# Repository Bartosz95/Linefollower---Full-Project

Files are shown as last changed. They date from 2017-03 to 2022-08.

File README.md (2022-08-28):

# Linefollowers

# Abstract 
Current repository contains three of my line follower projects.
Linefollower is a mobile robot which follows the line.
My robots were built for competitions so the main aim was to allow them to move fast.
Some of them were also remote controlled.
I've created these robots from top to bottom myself it means that I designed a board, created it, solder elements, create program for CPU and install it.

# Technologies
- KiCad
- STM32CubeMX
- Qt

# Description
As I mentioned current directory contains three robots
- BEBO - my first line follower which has PID algorithm
- LFANT - line follower which has spread encoders and mesure his speed
- Remote Controlled - this one is controlled by desktop remote app
To create these robots I had to do the same steps which I described below.

## Hardware
First I have to design a board. I've used a KiCad application to do it.
During this process I had to choose a CPU, engines, bridge for engine, battery, line sensors and all necessary elements.
I have chosen CPU STM32F051C8Tx because is enough small, 2 Pololu 10:1 engines, TB6612 bridge, Li-Pol 7,4V battery, line sensor KTIR0711s and depending on project AS5048A encoders or HC-06 bluetooth module.
Below you can see what it looks like designed boards ready to create.
<p align="center" float="left">
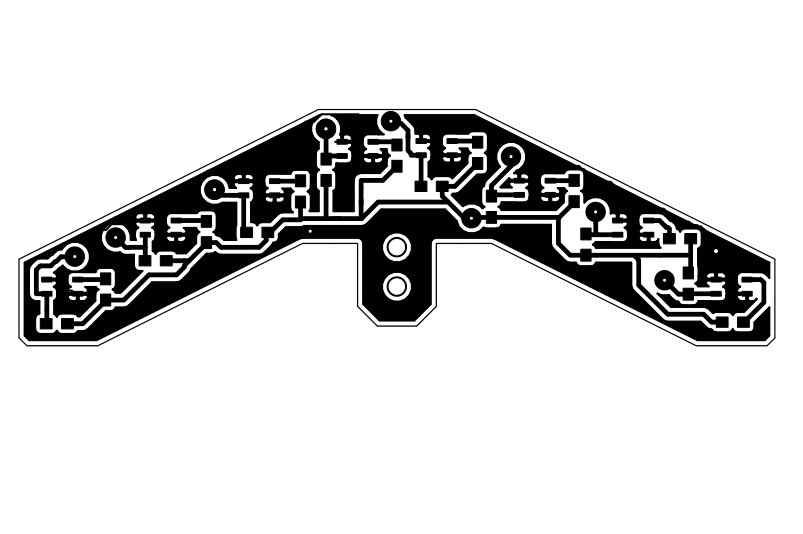
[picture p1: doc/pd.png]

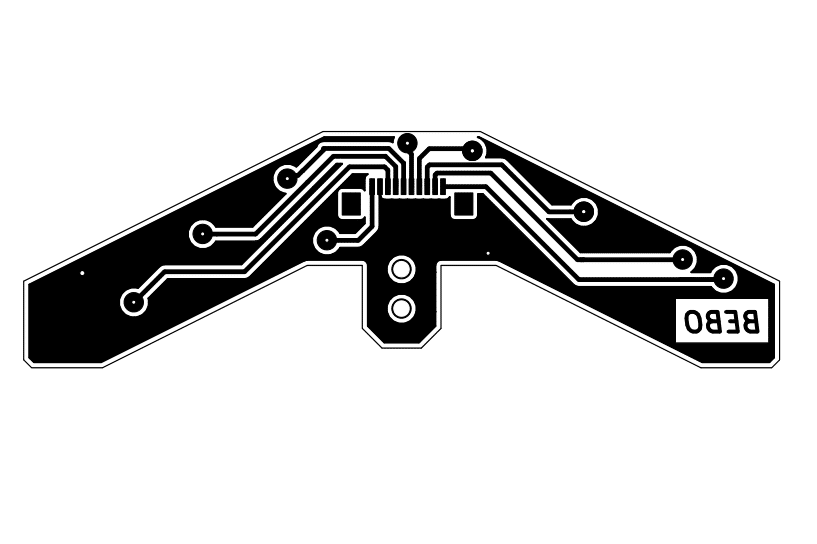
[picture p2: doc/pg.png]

</p>
<p align="center" float="left">
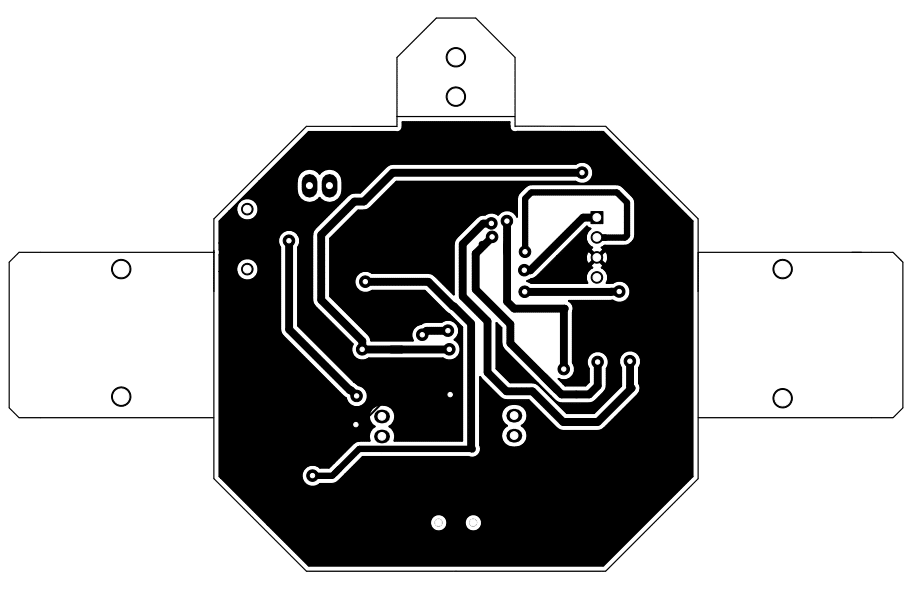
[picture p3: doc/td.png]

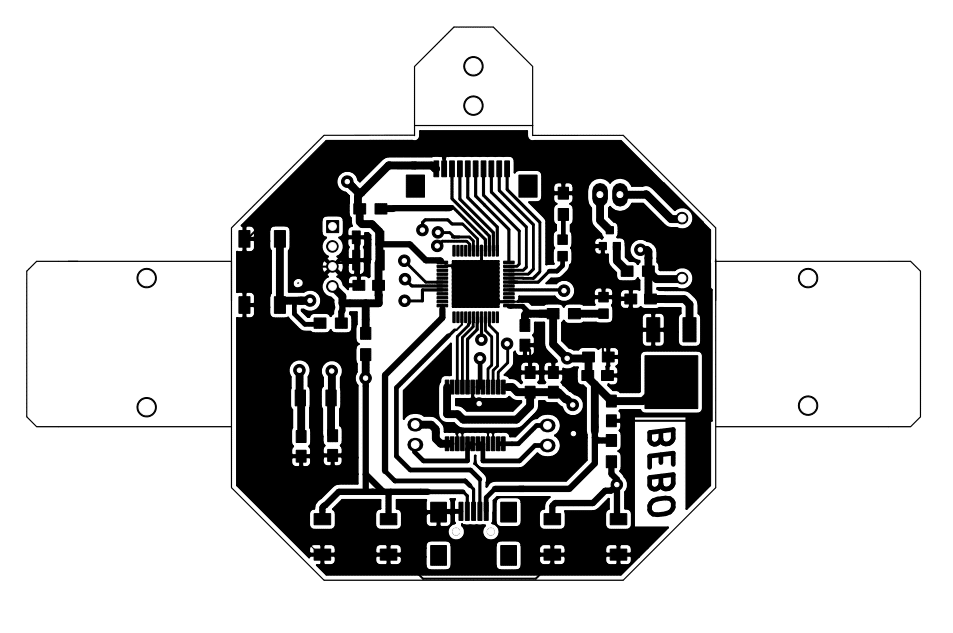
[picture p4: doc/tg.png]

</p>
In the next step I have to create this board and solder elements.
All
<p align="center" float="left">
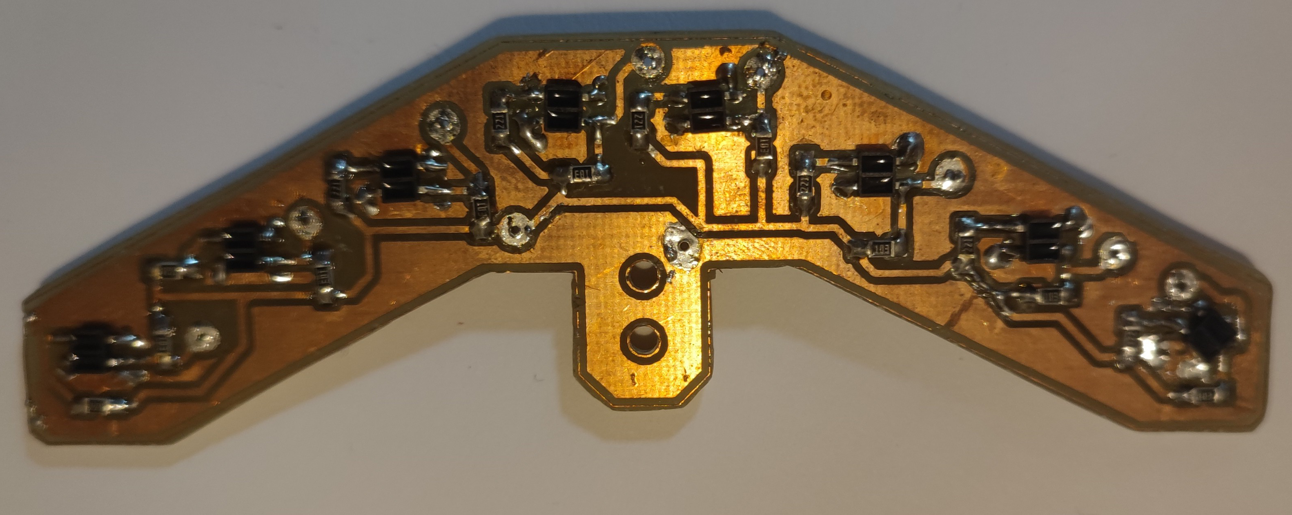
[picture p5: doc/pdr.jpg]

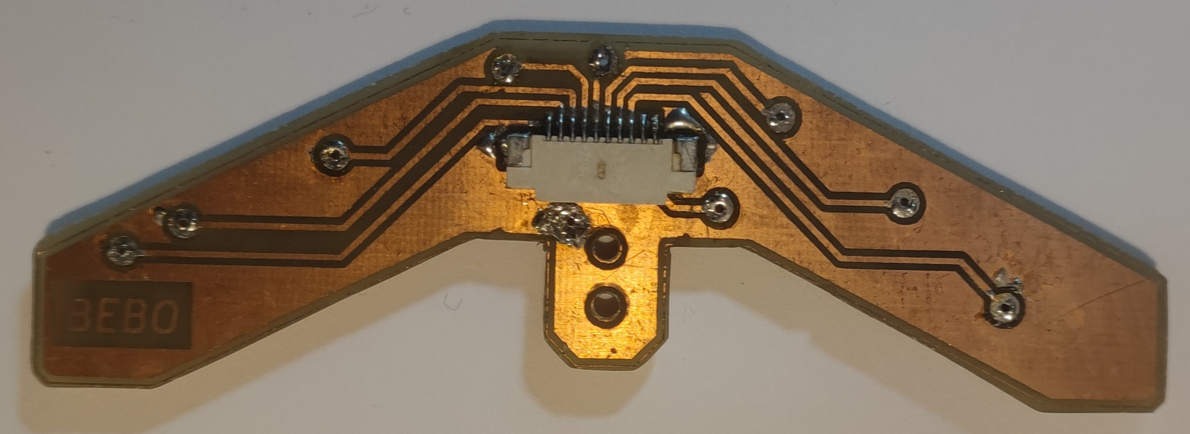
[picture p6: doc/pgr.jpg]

</p>
## Software
For creating software I decided to use the STM32CubeMX application.
It allows you to create programs for STM processors easily.
I assigned all necessary pins to the processor and created a controlled program.
When I finished programming it, I installed a program on robots by programator located on the STM32F4 board.
Created connection looks like below.
<p align="center" float="left">
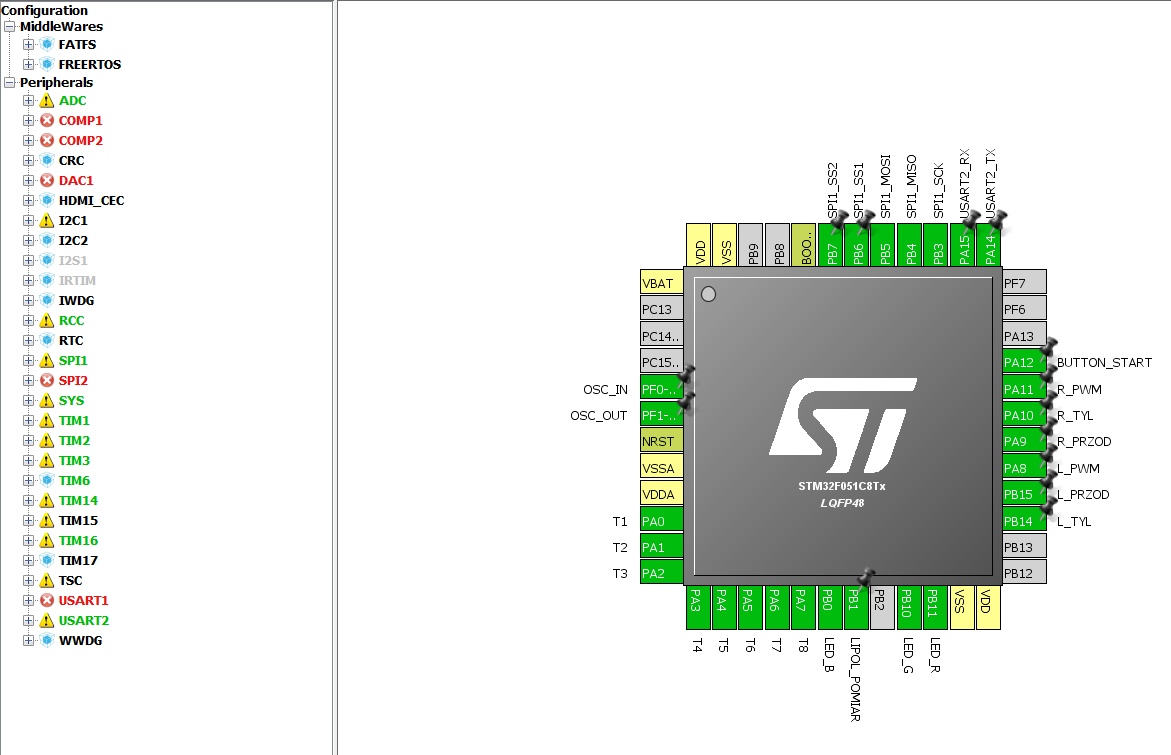
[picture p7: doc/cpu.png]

</p>
Ready robot looks like below.
<p align="center" float="left">
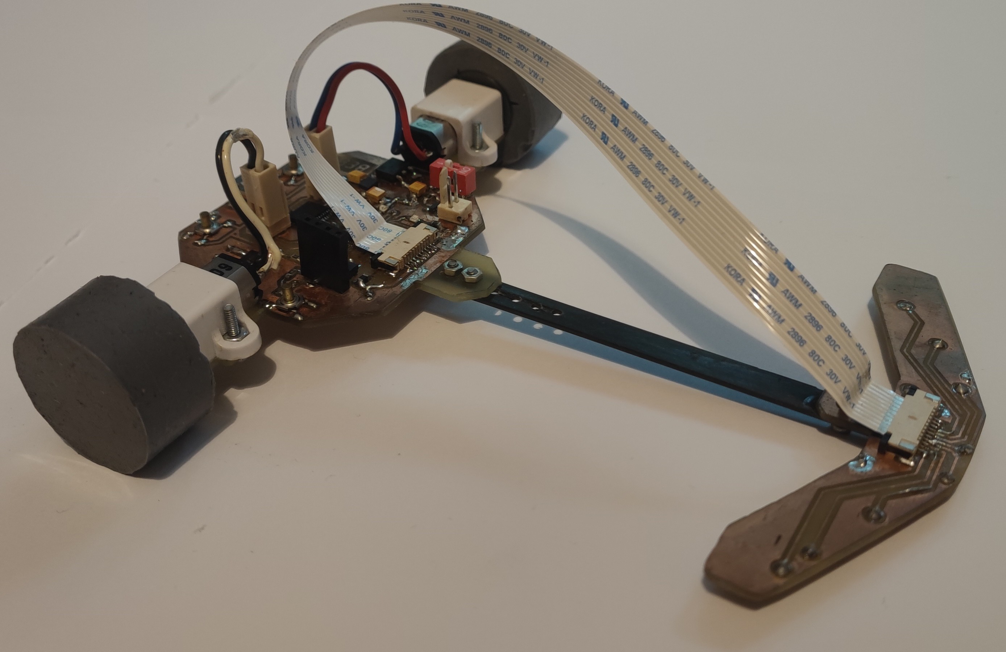
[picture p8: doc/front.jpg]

</p>
<p align="center" float="left">
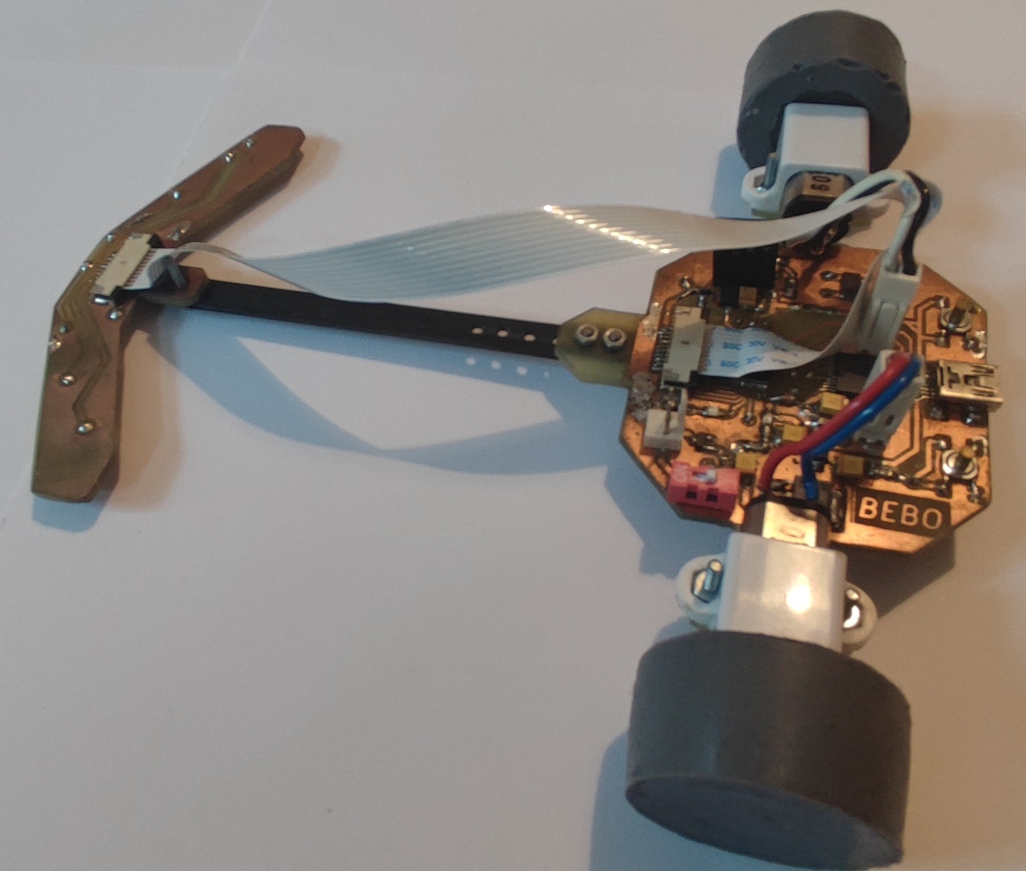
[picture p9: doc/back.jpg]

</p>

# Desktop application
For a remote controlled robot I created a program in C++ Qt. 
The connection works through bluetooth. Program works below.
The main window of the program is split vertically.
On the left side you can see measurements from the line follower.
On the right you have a control panel.
If each sensor detects a black line the circle of the top will change to black.
Below grey rectangles you can see 0. When a robot is moving it shows speed in mps.
In the control panel you have 5 buttons.
The one on the top change remote controlling to automatic control by PID algorithm,
The next four allow remote control robots. 
<p align="center" float="left">
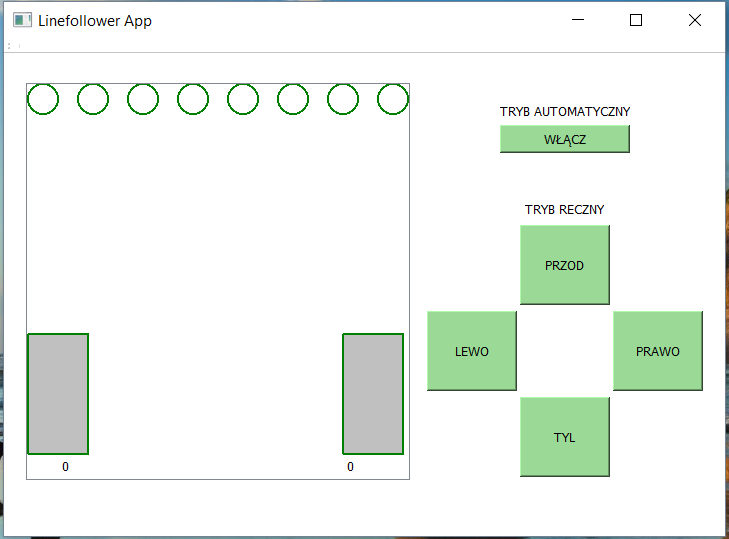
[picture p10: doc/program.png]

</p>

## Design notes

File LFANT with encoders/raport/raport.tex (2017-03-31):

% Definicja klasy dokumentu
\documentclass[12pt,a4paper]{article}

%------------------------------------
% 			Pakiety
\usepackage[utf8x]{inputenc}
\usepackage{ucs}
\usepackage[MeX]{polski}
\usepackage{fancyhdr}
\usepackage{amsmath}
\usepackage{amsfonts}
\usepackage{amssymb}
\usepackage[hidelinks]{hyperref}
\usepackage{graphicx}
\pagestyle{fancy}

%---------------------------------------
% 		Dodanie strony tytulowej do dokumentu
\input{tytulowa.tex} 

%-----------------------------------------
% 		Poczatek dokumentu
\begin{document}
\maketitle % Komenda maktitle dodaje stronę tytułową do dokumentu głównego
\tableofcontents % Komenda tableofcontents dodaje spis treści do dokumentu głównego
\newpage % Komenda newpage przechodzi do nowej strony w dokumencie.

%				Dokument wlasciwy
\section{Wstęp}

Celem projektu jest wykonanie robota mobilnego klasy linefollower. Zadaniem tego robota jest poruszanie się po czarnej linii na białym tle. Robot ma mieścić się na kartce A4. 

Robot będzie posiadał dwa enkodery AS5048A i komunikował się z nimi za pomocą interfejsu SPI.

\section{Założenia projektowe}
\begin{itemize}

\item Robot będzie składał się z 2 części - płytki głównej, na której będzie znajdował się mikrokontroler wraz z resztą elektroniki i akumulatorem oraz z płytki, na której będą czujniki odbiciowe. 

\item Napęd robota będą stanowiły 2 silniki Pololu.

\item Robot będzie zasilany przez akumulator Li-Pol o napięciu 7,4V i pojemności 300mAh.

\item Zabezpieczenie przed odwrotną polaryzacją w postaci tranzystora MOSFET oraz zabezpieczenie prądowe.

\item Pomiar napięcia baterii - sygnalizacja rozładowania się w postaci diody.

\item Projekt oparty o mikrokontroler STM32F051C8Tx, ponieważ jest mały, a posiada wystarczającą ilość potrzebnych peryferii.

\item 8 czujników odbiciowych KTIR0711s do wykrywania czarnej linii.

\item Silniki sterowane poprzez mostek TB6612.

\item Komunikacja z robotem będzie odbywała się przez moduł Bluetooth. 

\item 2 enkodery AS5048A obsługiwane za pomocą SPI.

Gdy uda się zrealizować powyższe założenia, w planie jest opcjonalne rozszerzenie projektu o dodanie:

\item turbiny ssącej

\item czujników odległośći Sharp

\end{itemize}

\section{Plan pracy}

\subsection{Harmonogram}

\begin{itemize}

\item Zaprojektowanie schematu - 16.04.2017

\item Zaprojektowanie płytki PCB - 7.05.2017

\item Wytrawiona i polutowana płytka - 14.05.2017

\item Wstępne zaprogramowanie robota - 4.06.2017

\item Testy gotowego programu - 18.06.2017

\item Raport końcowy - 22.06.2017

\end{itemize}

\subsection{Kamienie milowe}

\begin{itemize}
\item Zaprojektowana schematu - 16.04.2017

\item Rozpoczęcie programowania robota - 15.05.2017

\item Gotowy projekt wraz z raportem - 22.06.2017
\end{itemize}

\bibliographystyle{plunsrt}
\bibliography{mybib}
\clearpage
\end{document}

%Wzór numerowania

%\section{Punkt}
%\subsection{Podpunkt}

%Wzór dodawania obrazu

%\includegraphics[width=1\textwidth]{lipol.png}
%\caption{Schemat akumulatora \label{fig:lipol}}
%\end{figure}
%\begin{figure}[tp]
%\centering
%\includegraphics[width=1\textwidth]{stabilizator.png}
%\caption{Schemat stabilizatorów \label{fig:stabilizator}}
%\end{figure}

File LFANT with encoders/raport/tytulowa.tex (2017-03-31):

\renewcommand{\maketitle}{\begin{titlepage}

\begin{center}
%\vspace*{0.7cm}
\large \textsc{POLITECHNIKA WROCŁAWSKA}\\
\large \textsc{WYDZIAŁ ELEKTRONIKI}\\
\vspace*{4.7cm}
\huge \textsc{Sterowniki Robotów}\\
\vspace*{0.7cm}
\LARGE \textsc{Robot mobilny klasy linefollower}
\vspace*{0.7cm}

\vspace*{3cm}

\large

\textsc{Bartosz Lenartowicz} \\
\textsc{Magdalena Kaczorowska} \\

\vspace*{6cm}
\textsc{Wrocław, \today}\\
\end{center}
\end{titlepage}
\newpage
}

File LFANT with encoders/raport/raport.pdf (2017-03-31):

POLITECHNIKA WROCŁAWSKA

WYDZIAŁ ELEKTRONIKI

### Sterowniki Robotów

Robot mobilny klasy linefollower

Bartosz Lenartowicz

Magdalena Kaczorowska

Wrocław, 31 marca 2017

SPIS TREŚCI | SPIS TREŚCI

## Spis treści

1 Wstęp | 2
2 Założenia projektowe | 2
3 Plan pracy | 3

1

2 ZAŁOŻENIA PROJEKTOWE

## 1 Wstęp

Celem projektu jest wykonanie robota mobilnego klasy linefollower. Zadaniem tego robota jest poruszanie się po czarnej linii na białym tle. Robot ma mieścić się na kartce A4.
Robot będzie posiadał dwa enkodery AS5048A i komunikował się z nimi za pomocą interfejsu SPI.

## 2 Założenia projektowe

- Robot będzie składał się z 2 części - płytki głównej, na której będzie znajdował się mikrokontroler wraz z resztą elektroniki i akumulatorem oraz z płytki, na której będą czujniki odbiciowe.
- Napęd robota będą stanowiły 2 silniki Pololu.
- Robot będzie zasilany przez akumulator Li-Pol o napięciu 7,4V i pojemności 300mAh.
- Zabezpieczenie przed odwrotną polaryzacją w postaci tranzystora MOS-FET oraz zabezpieczenie prądowe.
- Pomiar napięcia baterii - sygnalizacja rozładowania się w postaci diody.
- Projekt oparty o mikrokontroler STM32F051C8Tx, ponieważ jest mały, a posiada wystarczającą ilość potrzebnych peryferii.
- 8 czujników odbiciowych KTIR0711s do wykrywania czarnej linii.
- Silniki sterowane poprzez mostek TB6612.
- Komunikacja z robotem będzie odbywała się przez moduł Bluetooth.
- 2 enkodery AS5048A obsługiwane za pomocą SPI.

Gdy uda się zrealizować powyższe założenia, w planie jest opcjonalne rozszerzenie projektu o dodanie:

- turbiny ssącej
- czujników odległośći Sharp

2

3 PLAN PRACY

## 3 Plan pracy

### 3.1 Harmonogram

- Zaprojektowanie schematu - 16.04.2017
- Zaprojektowanie płytki PCB - 7.05.2017
- Wytrawiona i polutowana płytka - 14.05.2017
- Wstępne zaprogramowanie robota - 4.06.2017
- Testy gotowego programu - 18.06.2017
- Raport końcowy - 22.06.2017

### 3.2 Kamienie milowe

- Zaprojektowana schematu - 16.04.2017
- Rozpoczęcie programowania robota - 15.05.2017
- Gotowy projekt wraz z raportem - 22.06.2017

3

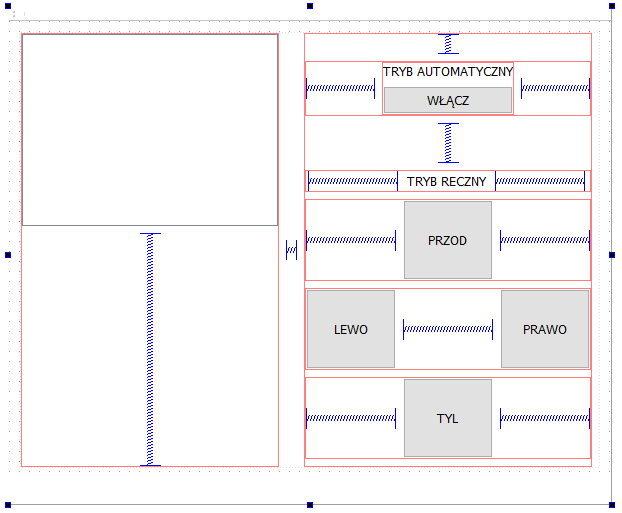
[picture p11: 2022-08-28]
doc/Okno.PNG

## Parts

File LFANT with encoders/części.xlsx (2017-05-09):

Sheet: Arkusz1
Botland
Nazwa | ilosc | cena za sztukę | razem
Silnik Pololu | 2 | 72 | 144
Ball Caster | 2 | 7.9 | 15.8
KTIR0711S | 10 | 1.95 | 19.5
mocowanie silnika | 1 | 17.9 | 17.9
Razem: |  |  | 197.2
Nie wybrane
bezpiecznik
przelacznik on/off

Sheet: Arkusz2
Elektropark
Nazwa | ilosc | cena za sztukę | razem
TB6612 | 2 | 13.99 | 27.98
LED Biała | 3 | 0.49 | 1.47
LED RGB | 1 | 0.99 | 0.99
Kwarc 8MHz | 3 | 1.8 | 5.4
Taśma FFC 11cm | 1 | 3.51 | 3.51
Taśma FFC 21cm | 1 | 4.4 | 4.4
Złącze FFC/FPC | 2 | 2.5 | 5
Przełącznik ON/ON | 2 | 2.24 | 4.48
IRML0030 N Mosfet | 3 | 0.69 | 2.07
R33k | 1 | 0.3 | 0.3
R47k | 2 | 0.3 | 0.6
R1k | 1 | 0.3 | 0.3
R220R | 3 | 0.3 | 0.9
R10k | 5 | 0.3 | 1.5
R1k | 1 | 0.3 | 0.3
R150k | 1 | 0.3 | 0.3
R13k | 1 | 0.3 | 0.3
R22k | 1 | 0.3 | 0.3
R62k | 1 | 0.3 | 0.3
USB typ B smd mini | 3 | 1.01 | 3.03
C22pF | 1 | 0.39 | 0.39
C100nF | 2 | 0.39 | 0.78
C10nF | 1 | 0.45 | 0.45
C4,7 | 2 | 0.85 | 1.7
C10uF | 2 | 0.8 | 1.6
LF33 3.3V | 3 | 3 | 9
LM1117 5V | 3 | 1.35 | 4.05
Laminat św/150x200/2 | 1 | 42.99 | 42.99
Laminat św/75x100/2 | 1 | 9 | 9
Razem: |  |  | 133.39

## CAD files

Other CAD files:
LFANT with encoders/Inventor/mocowania_magnesów.ipt

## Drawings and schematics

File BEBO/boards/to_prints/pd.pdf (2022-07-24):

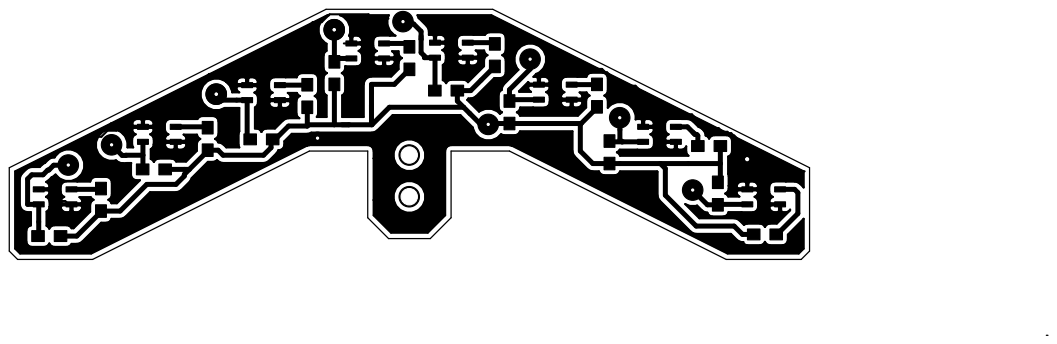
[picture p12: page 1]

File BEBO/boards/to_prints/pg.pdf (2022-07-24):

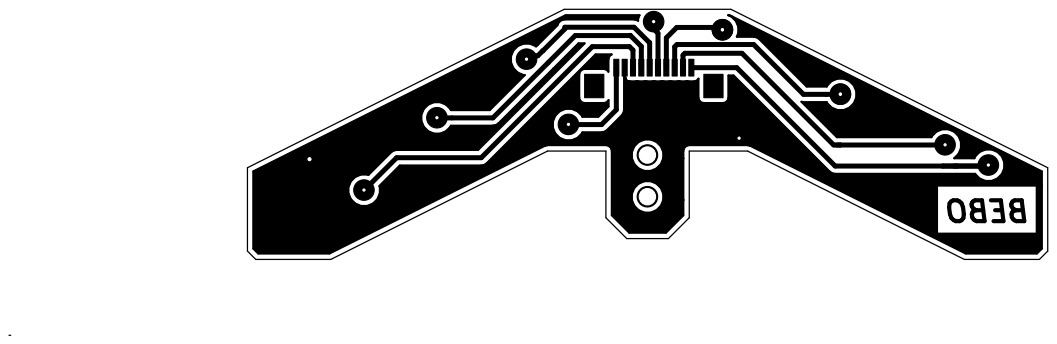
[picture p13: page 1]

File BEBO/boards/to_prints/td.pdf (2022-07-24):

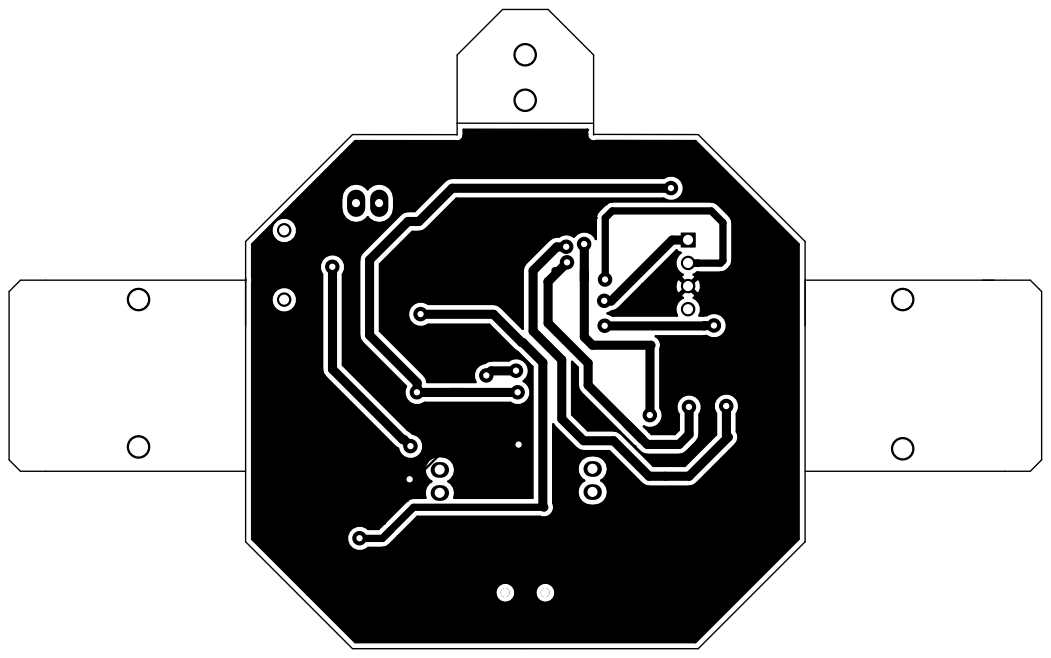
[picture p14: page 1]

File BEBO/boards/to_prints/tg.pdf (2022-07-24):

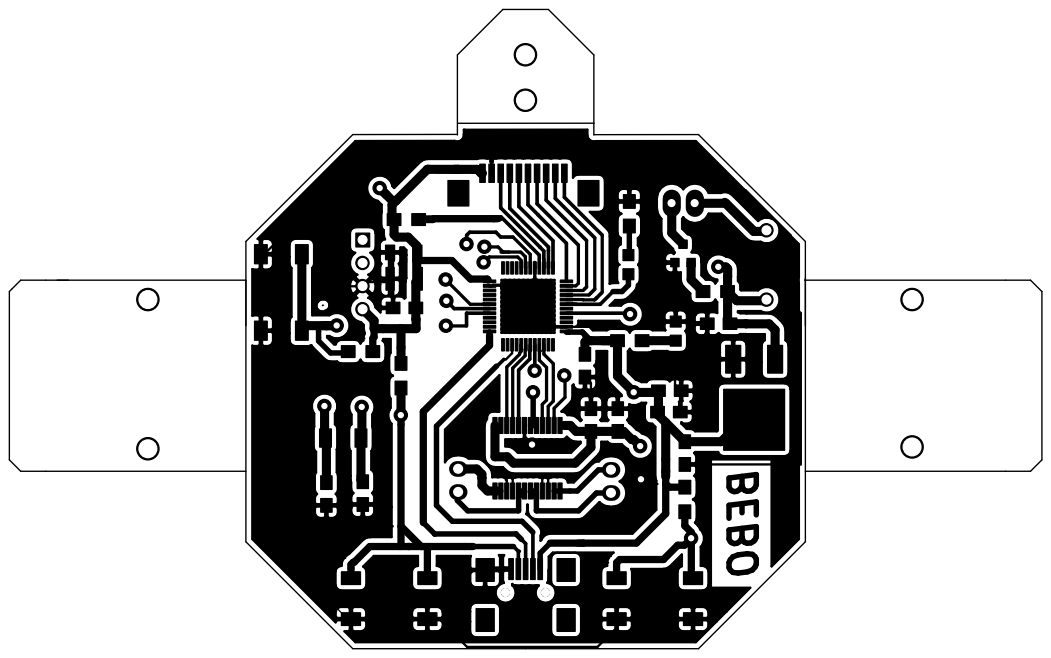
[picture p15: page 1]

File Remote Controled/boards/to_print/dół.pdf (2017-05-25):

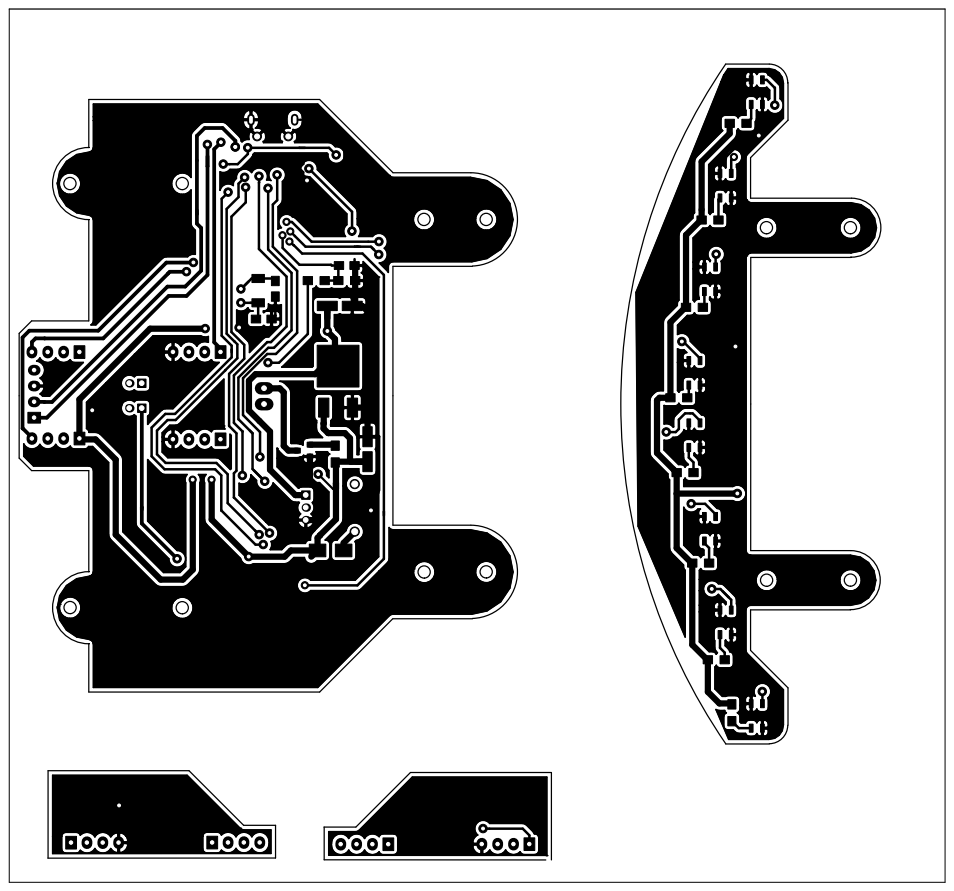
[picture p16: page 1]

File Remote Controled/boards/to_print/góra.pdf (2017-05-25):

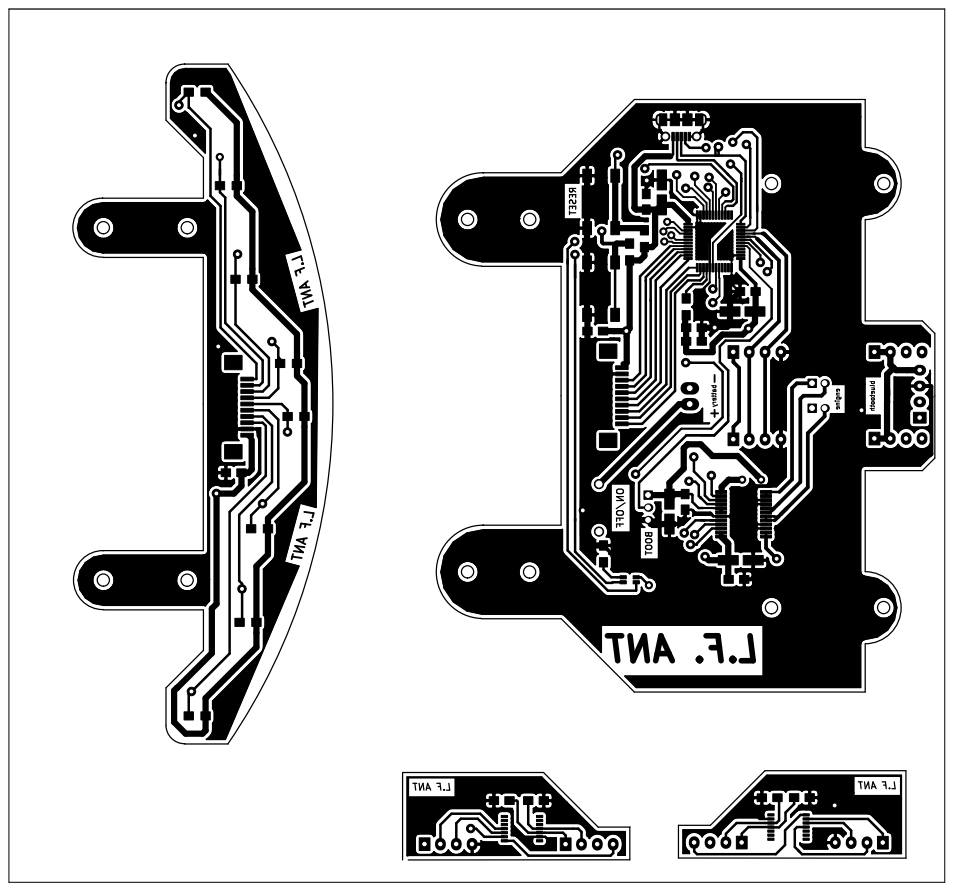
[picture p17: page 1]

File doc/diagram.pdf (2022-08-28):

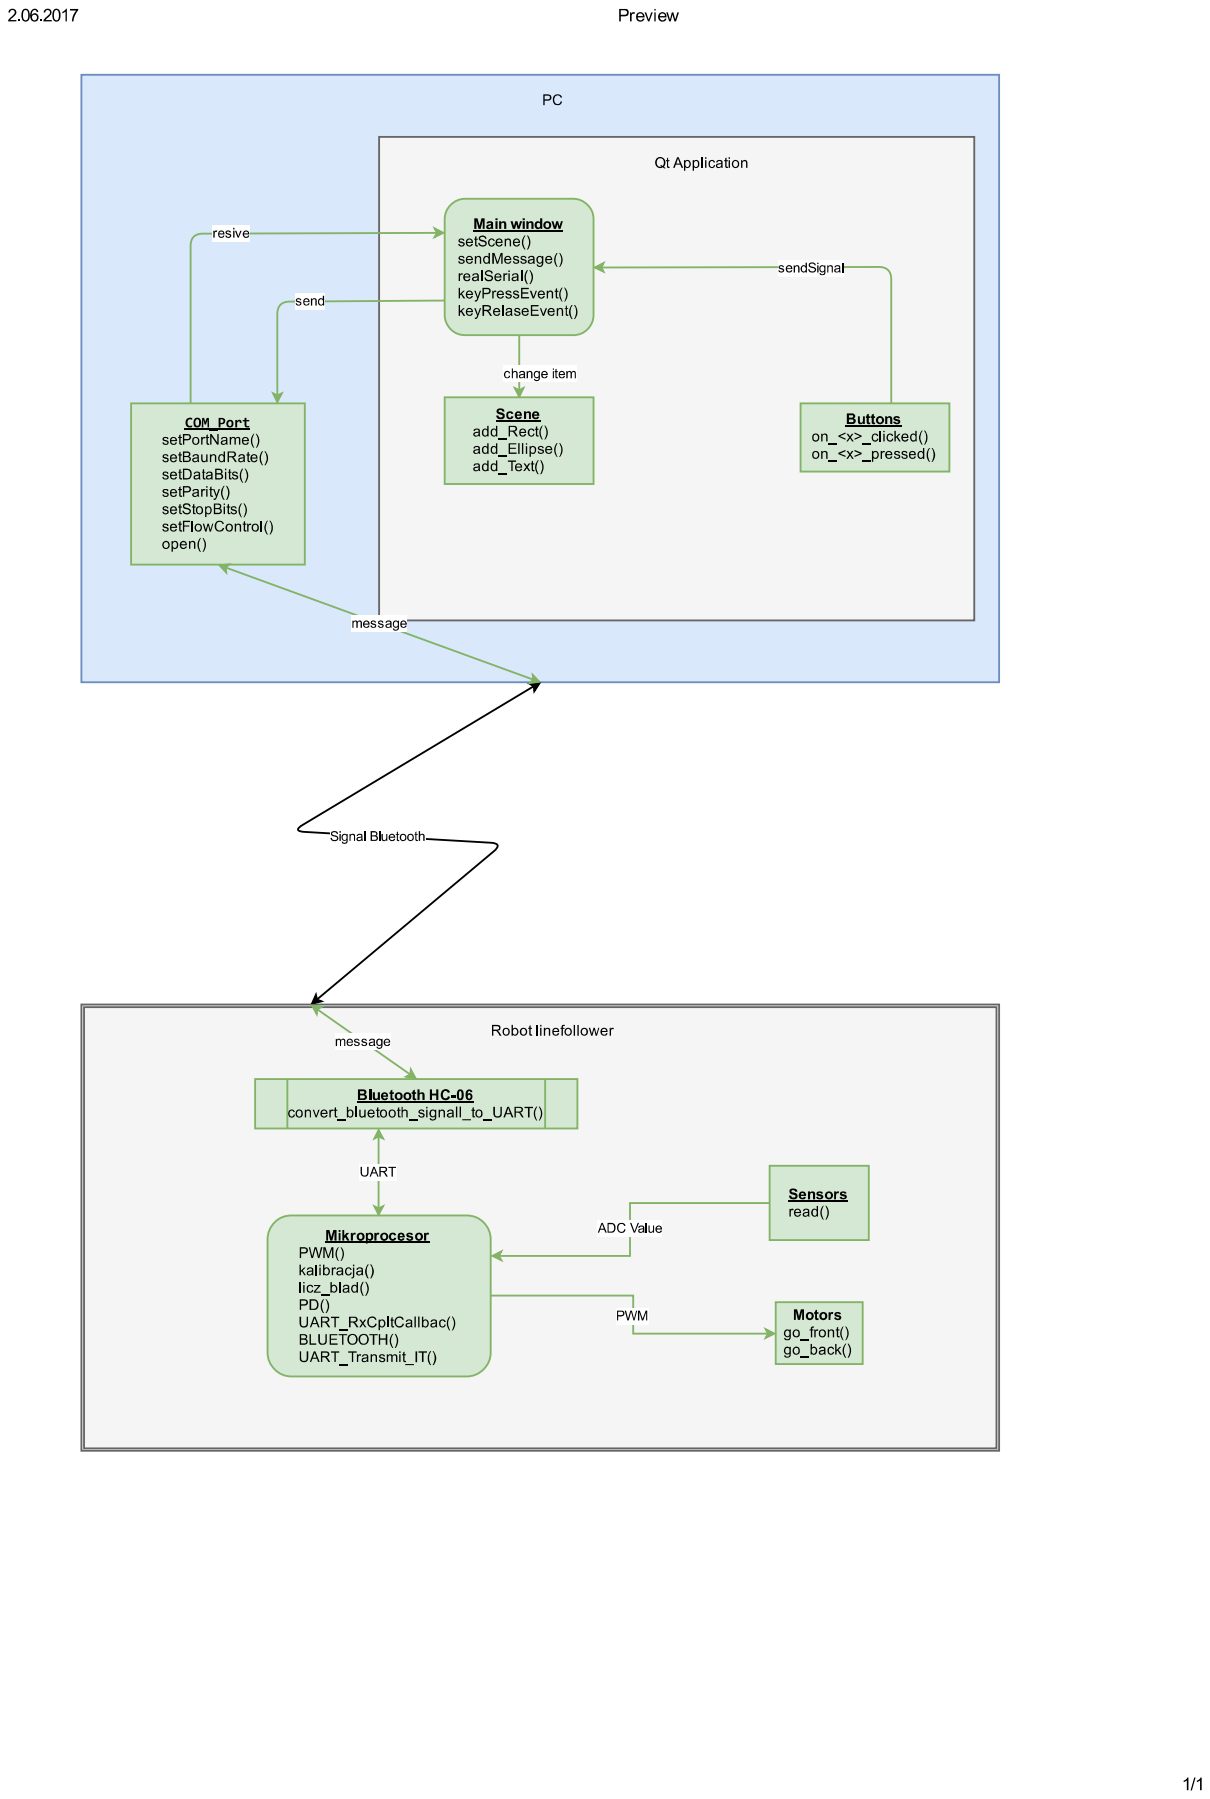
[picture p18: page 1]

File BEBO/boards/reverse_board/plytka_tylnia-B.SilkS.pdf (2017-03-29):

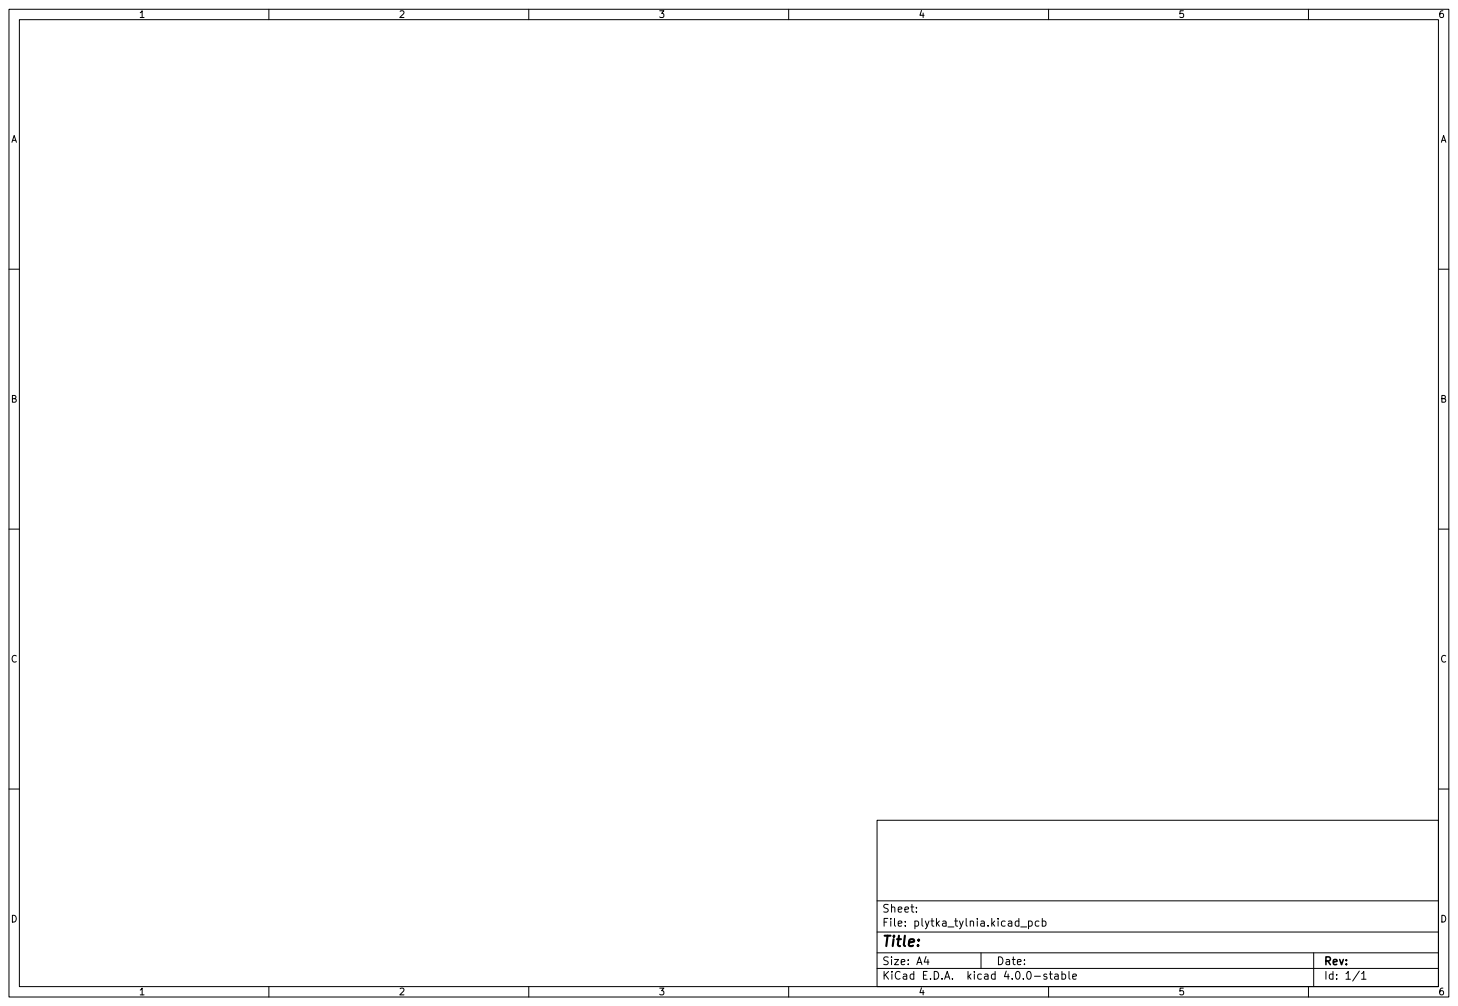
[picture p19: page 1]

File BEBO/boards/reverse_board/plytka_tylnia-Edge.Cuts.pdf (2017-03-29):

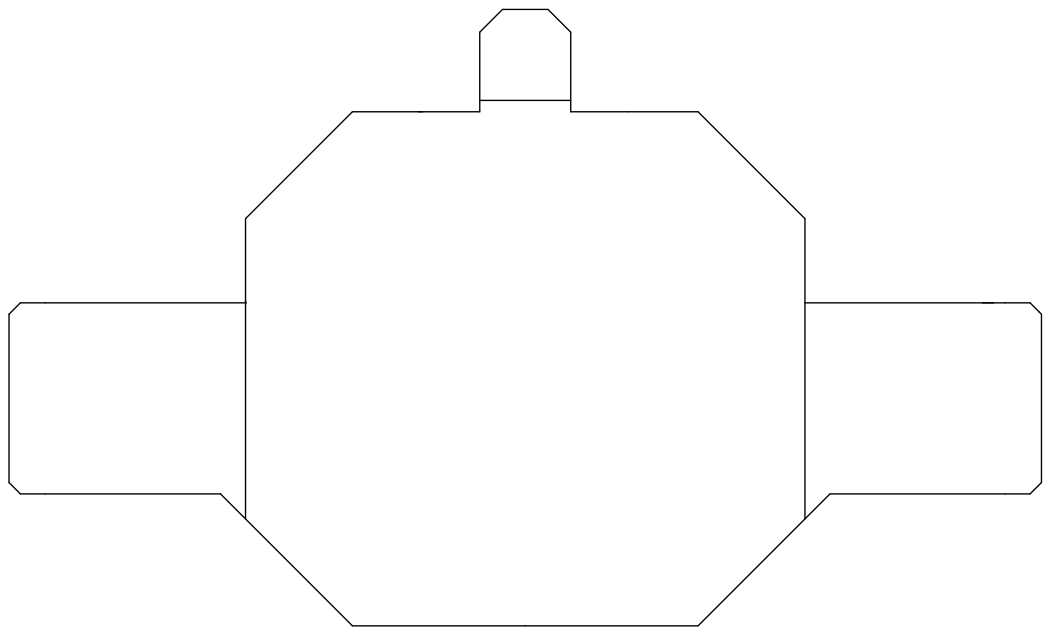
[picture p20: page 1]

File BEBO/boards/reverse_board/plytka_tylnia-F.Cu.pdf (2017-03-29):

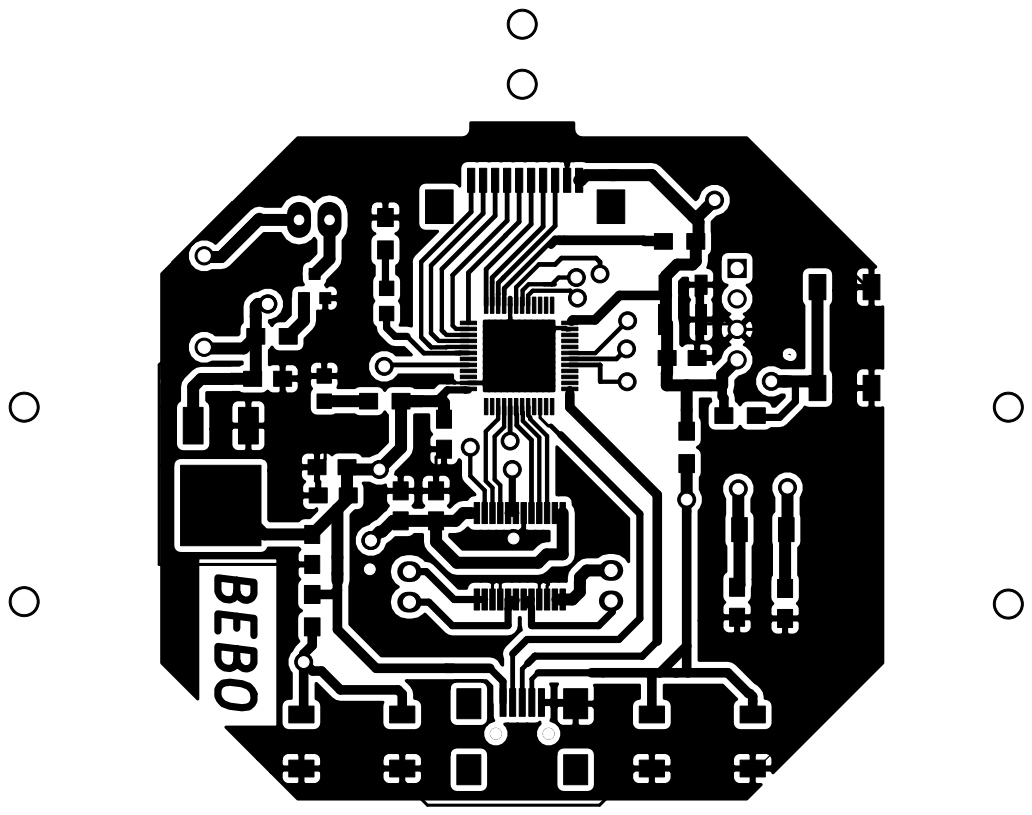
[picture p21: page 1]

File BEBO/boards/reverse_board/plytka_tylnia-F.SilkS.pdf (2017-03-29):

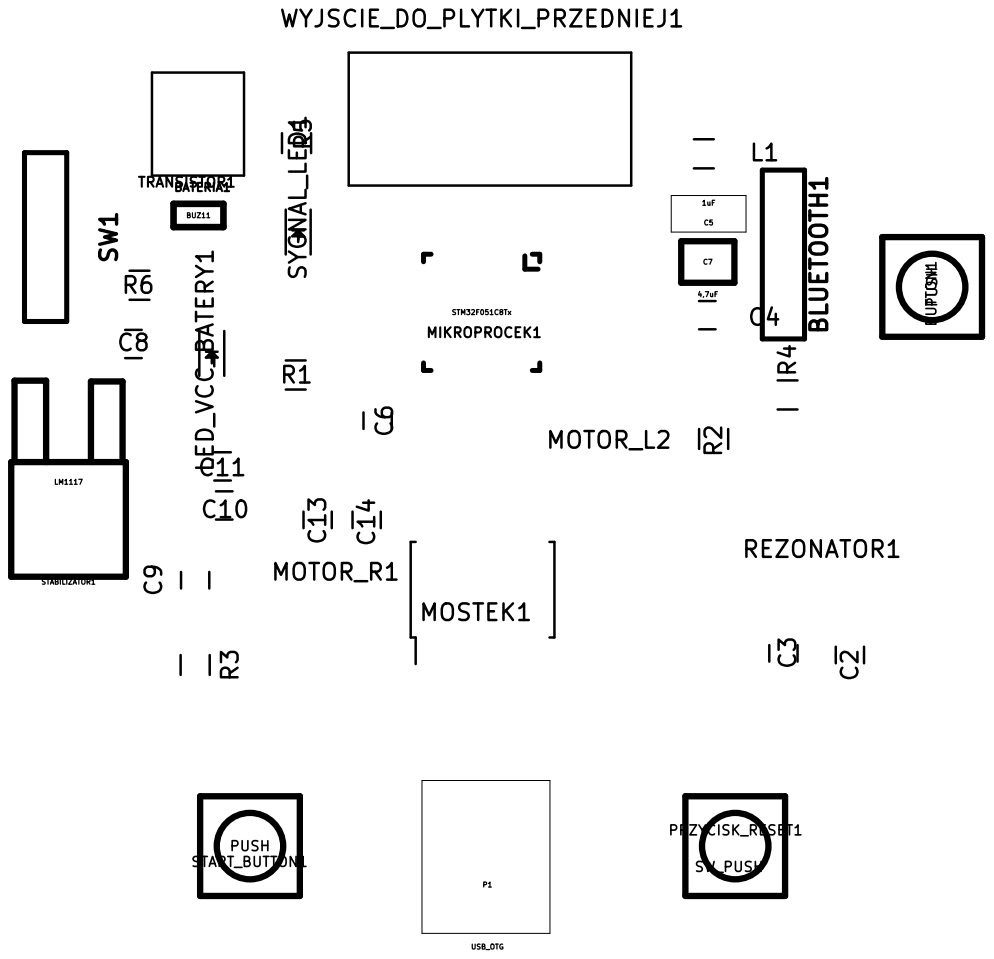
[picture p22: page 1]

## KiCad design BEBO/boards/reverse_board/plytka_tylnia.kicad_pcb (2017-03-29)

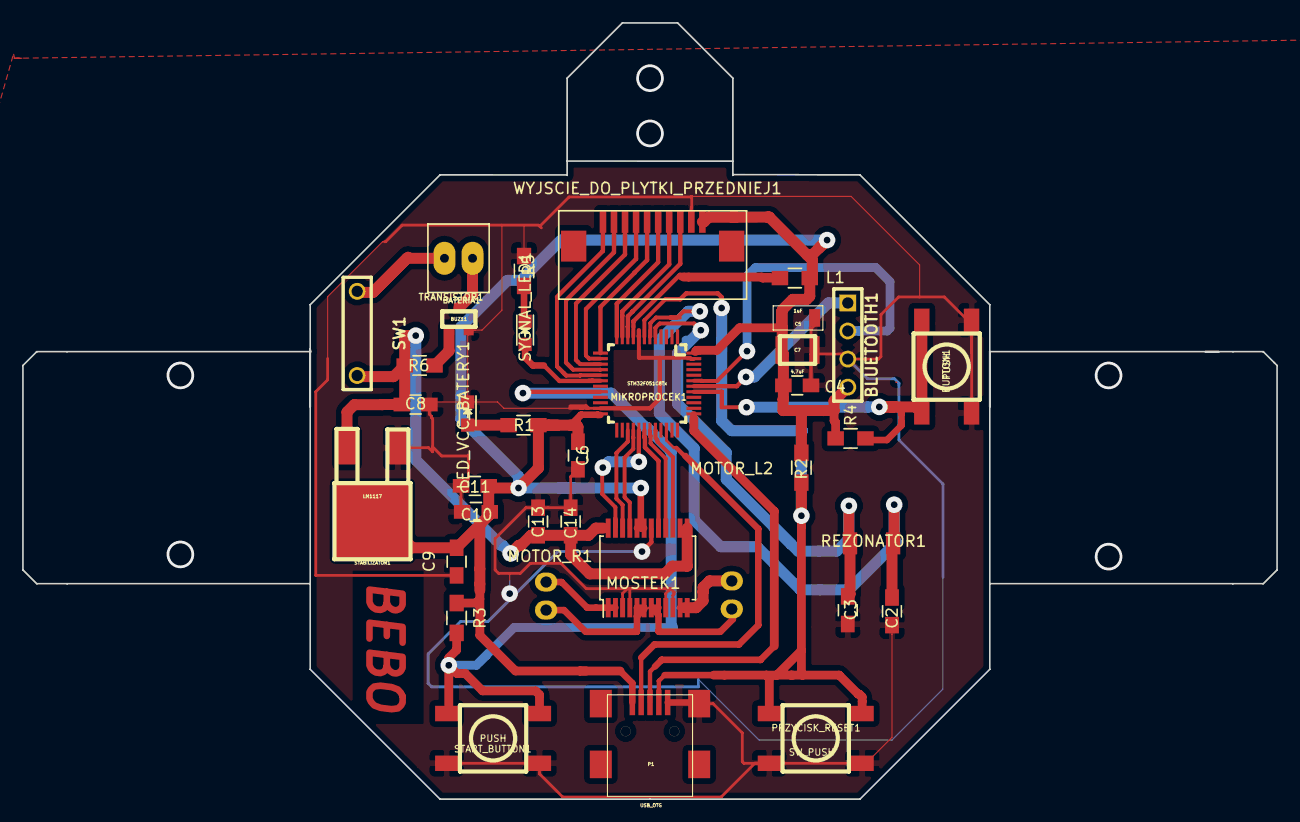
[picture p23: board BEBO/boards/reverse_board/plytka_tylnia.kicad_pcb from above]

Board: 2 copper layers, 113.5 x 70.2 mm, 36 parts (0 on the bottom side), 37 nets.

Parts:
BATERIA1: LI-POL; zl_zasilania
BLUETOOTH1: PIN4; pin_array_4x1
BUTTON1: PUSH; SW_06_SMD
C2, C3: 22pF; C_0805_HandSoldering
C4: 10nF; C_0805_HandSoldering
C5: 1uF; 1206
C6: 100nF; C_0805_HandSoldering
C7: 4,7uF; 1210
C8, C9, C11, C14: 10uF; C_0805_HandSoldering
C10: 1uF; C_0805_HandSoldering
C13: 0.1uF; C_0805_HandSoldering
L1: 10uH; R_0805_HandSoldering
LED_VCC_BATERY1: LED_GREEN; LED_0805
MIKROPROCEK1: STM32F051C8Tx; LQFP48
MOSTEK1: TB6612
MOTOR_L2: PIN2; silnik
MOTOR_R1: PIN2; silnik
P1: USB_OTG; USB-MINI-B-SMD
PRZYCISK_RESET1: SW_PUSH; SW_06_SMD
R1, R5: 200; R_0805_HandSoldering
R2, R3, R4: 10k; R_0805_HandSoldering
R6: 1k; R_0805_HandSoldering
REZONATOR1: HC49-S; Kwarc_SMD_Mini
STABILIZATOR1: LM1117; LM1117_TO-252
START_BUTTON1: PUSH; SW_06_SMD
SW1: SPST; dip_switch_1
SYGNAL_LED1: LED_BLUE; LED_0805
TRANSISTOR1: BUZ11; SOT23-3
WYJSCIE_DO_PLYTKI_PRZEDNIEJ1: PIN10; fpc_10_pin

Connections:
/BATERIA: C8.1, C13.2, C14.1, MOSTEK1.13, MOSTEK1.14, MOSTEK1.24, R6.2, STABILIZATOR1.1, SW1.2
/L_IN1: MIKROPROCEK1.27, MOSTEK1.22
/L_IN2: MIKROPROCEK1.28, MOSTEK1.21
/L_PWM: MIKROPROCEK1.29, MOSTEK1.23
/RESET: MIKROPROCEK1.7, P1.4, PRZYCISK_RESET1.1, R2.2
/R_IN1: MIKROPROCEK1.31, MOSTEK1.16
/R_IN2: MIKROPROCEK1.30, MOSTEK1.17
/R_PWM: MIKROPROCEK1.32, MOSTEK1.15
/SWCLK: MIKROPROCEK1.37, P1.3
/SWDIO: MIKROPROCEK1.34, P1.2
/T1: MIKROPROCEK1.10, WYJSCIE_DO_PLYTKI_PRZEDNIEJ1.8
/T2: MIKROPROCEK1.11, WYJSCIE_DO_PLYTKI_PRZEDNIEJ1.7
/T3: MIKROPROCEK1.12, WYJSCIE_DO_PLYTKI_PRZEDNIEJ1.6
/T4: MIKROPROCEK1.13, WYJSCIE_DO_PLYTKI_PRZEDNIEJ1.5
/T5: MIKROPROCEK1.14, WYJSCIE_DO_PLYTKI_PRZEDNIEJ1.4
/T6: MIKROPROCEK1.15, WYJSCIE_DO_PLYTKI_PRZEDNIEJ1.3
/T7: MIKROPROCEK1.16, WYJSCIE_DO_PLYTKI_PRZEDNIEJ1.2
/T8: MIKROPROCEK1.17, WYJSCIE_DO_PLYTKI_PRZEDNIEJ1.1
/USART_RX: BLUETOOTH1.1, MIKROPROCEK1.42
/USART_TX: BLUETOOTH1.2, MIKROPROCEK1.43
GND: BLUETOOTH1.3, BUTTON1.1, C2.2, C3.2, C4.2, C5.2, C6.2, C7.2, C8.2, C9.2, C10.2, C11.1, C13.1, C14.2, LED_VCC_BATERY1.1, MIKROPROCEK1.8, MIKROPROCEK1.23, MIKROPROCEK1.47, MOSTEK1.3, MOSTEK1.4, MOSTEK1.9, MOSTEK1.10, MOSTEK1.18, P1.5, P1.6, PRZYCISK_RESET1.2, R5.2, STABILIZATOR1.3, START_BUTTON1.1, TRANSISTOR1.2, WYJSCIE_DO_PLYTKI_PRZEDNIEJ1.9
unnamed: BATERIA1.1, TRANSISTOR1.3
unnamed: BATERIA1.2, SW1.1
unnamed: BUTTON1.2, MIKROPROCEK1.41, R4.2
unnamed: C3.1, MIKROPROCEK1.5, REZONATOR1.1
unnamed: C2.1, MIKROPROCEK1.6, REZONATOR1.2
unnamed: R6.1, TRANSISTOR1.1
unnamed: L1.2, MIKROPROCEK1.9
unnamed: LED_VCC_BATERY1.2, R1.1
unnamed: MIKROPROCEK1.20, R3.2, START_BUTTON1.2
unnamed: MIKROPROCEK1.18, SYGNAL_LED1.2
unnamed: MOSTEK1.1, MOSTEK1.2, MOTOR_R1.1
unnamed: MOSTEK1.5, MOSTEK1.6, MOTOR_R1.2
unnamed: MOSTEK1.7, MOSTEK1.8, MOTOR_L2.2
unnamed: MOSTEK1.11, MOSTEK1.12, MOTOR_L2.1
unnamed: R5.1, SYGNAL_LED1.1
VCC: BLUETOOTH1.4, C4.1, C5.1, C6.1, C7.1, C9.1, C10.1, C11.2, L1.1, MIKROPROCEK1.24, MIKROPROCEK1.48, MOSTEK1.19, MOSTEK1.20, P1.1, R1.2, R2.1, R3.1, R4.1, STABILIZATOR1.2, WYJSCIE_DO_PLYTKI_PRZEDNIEJ1.10

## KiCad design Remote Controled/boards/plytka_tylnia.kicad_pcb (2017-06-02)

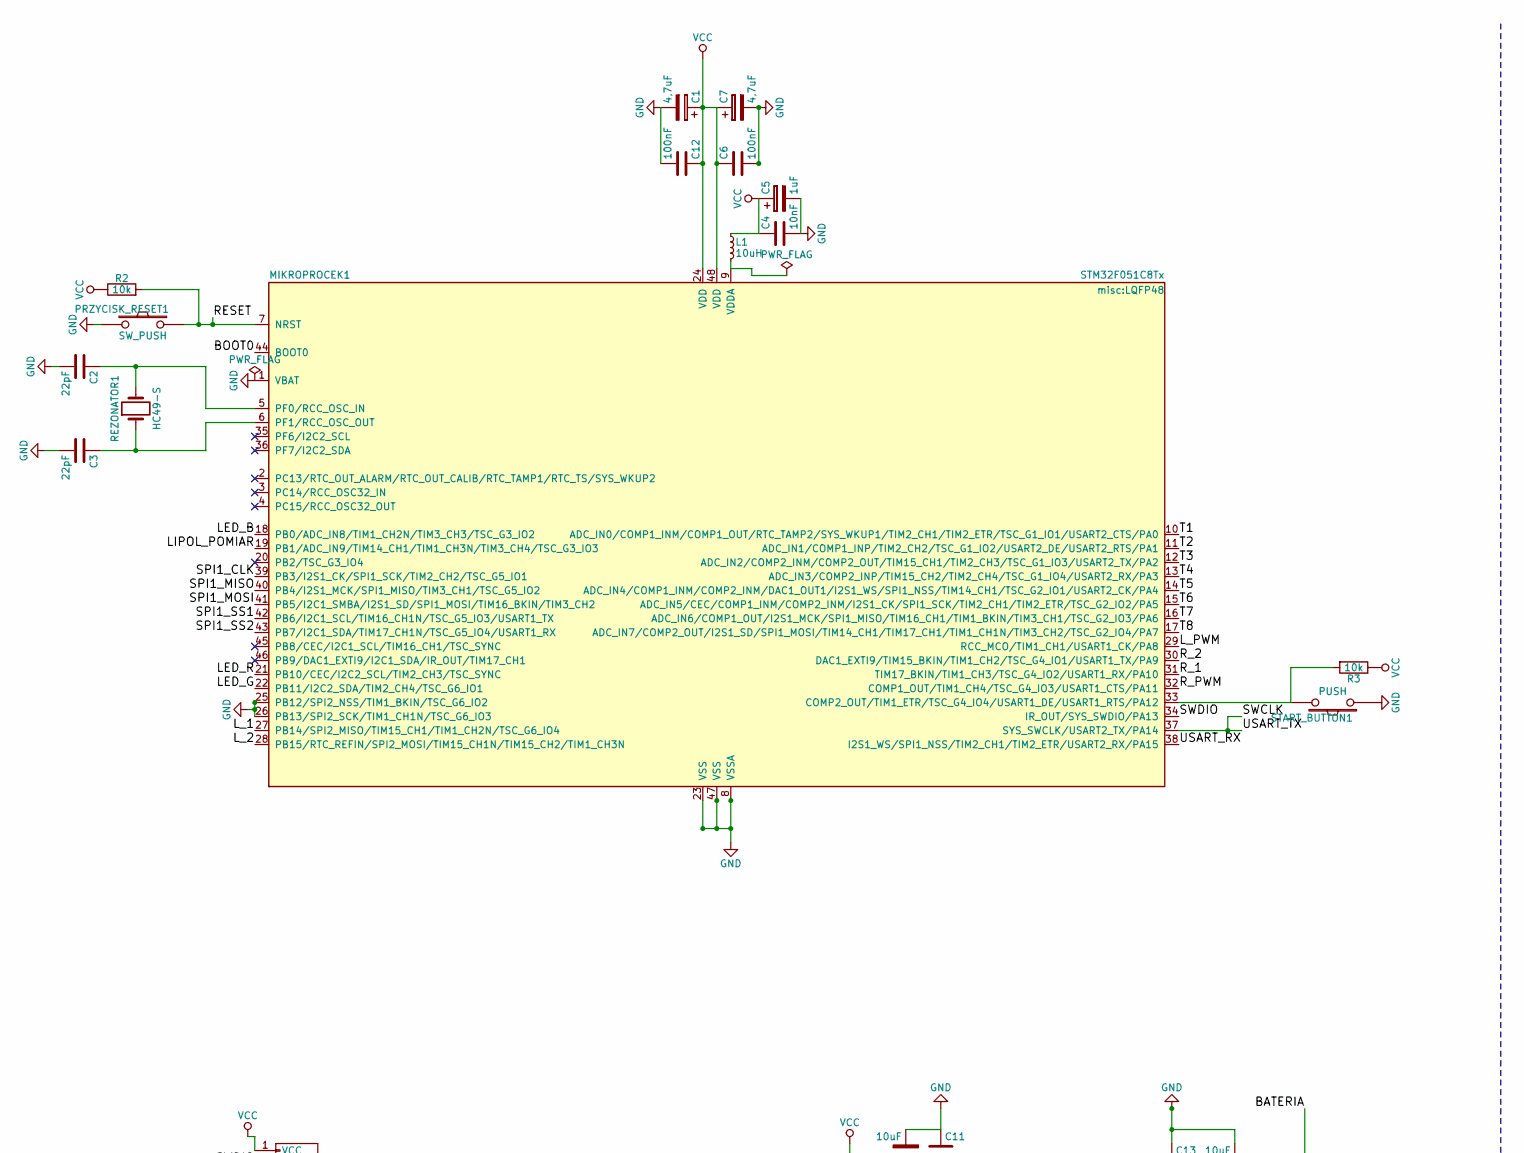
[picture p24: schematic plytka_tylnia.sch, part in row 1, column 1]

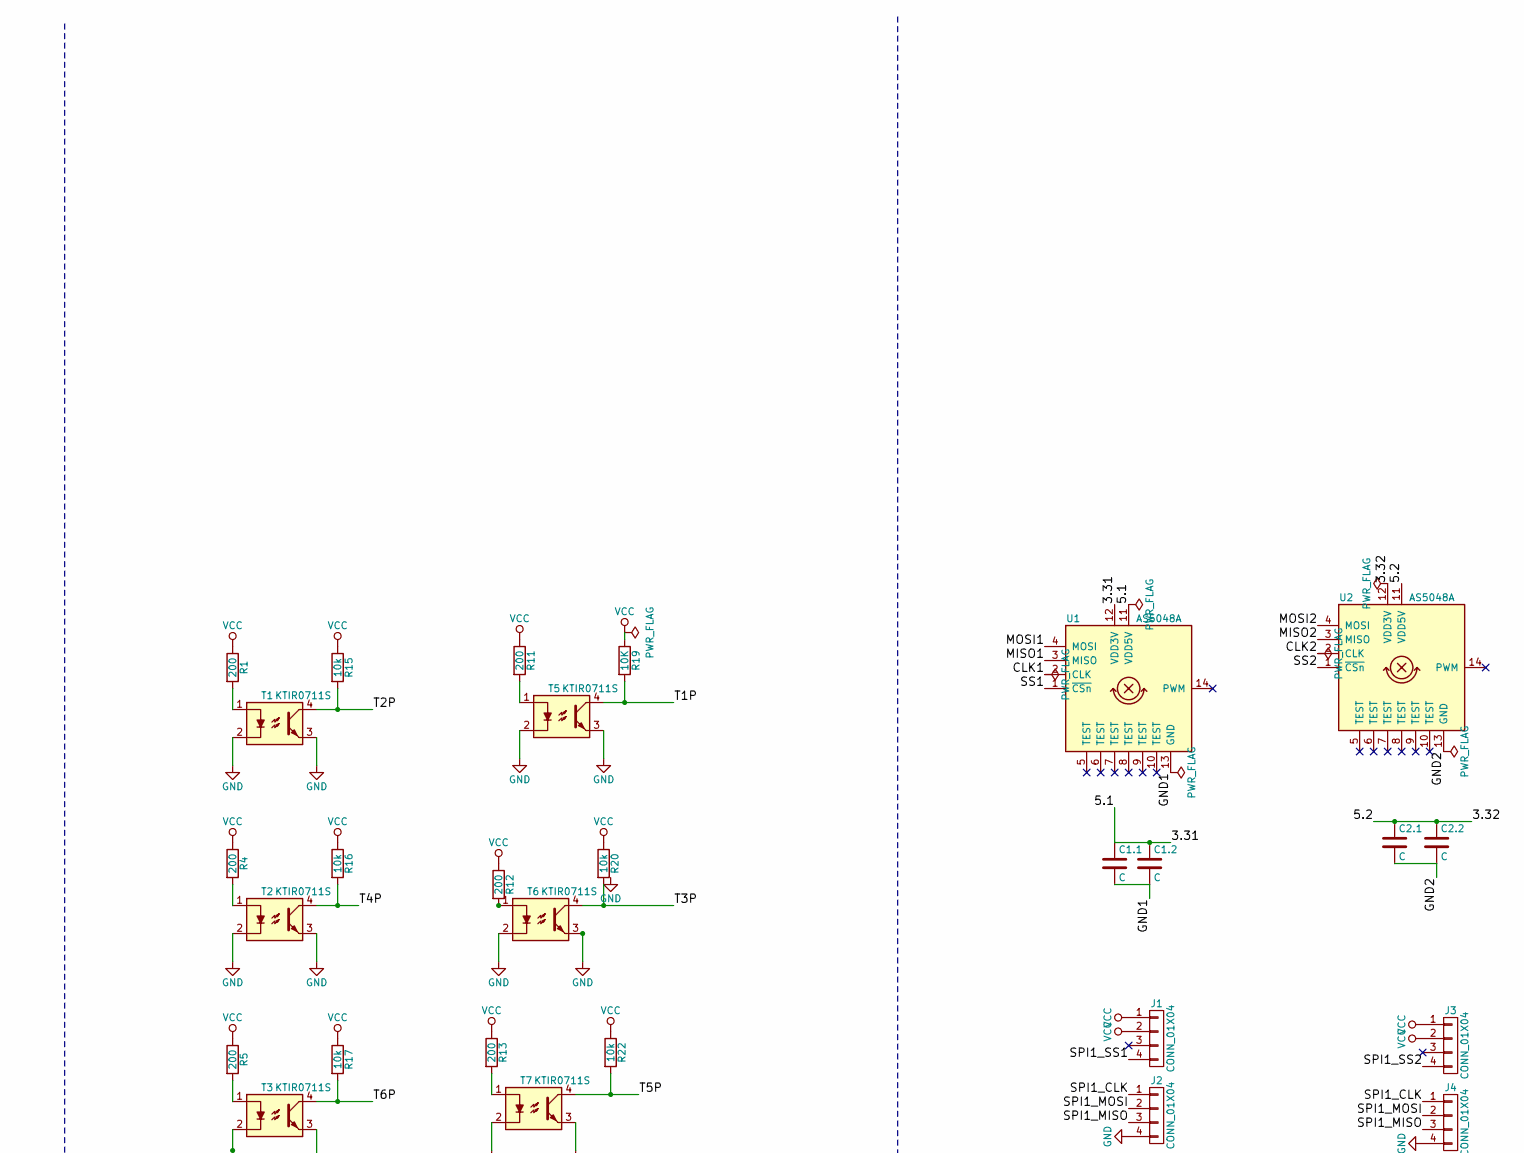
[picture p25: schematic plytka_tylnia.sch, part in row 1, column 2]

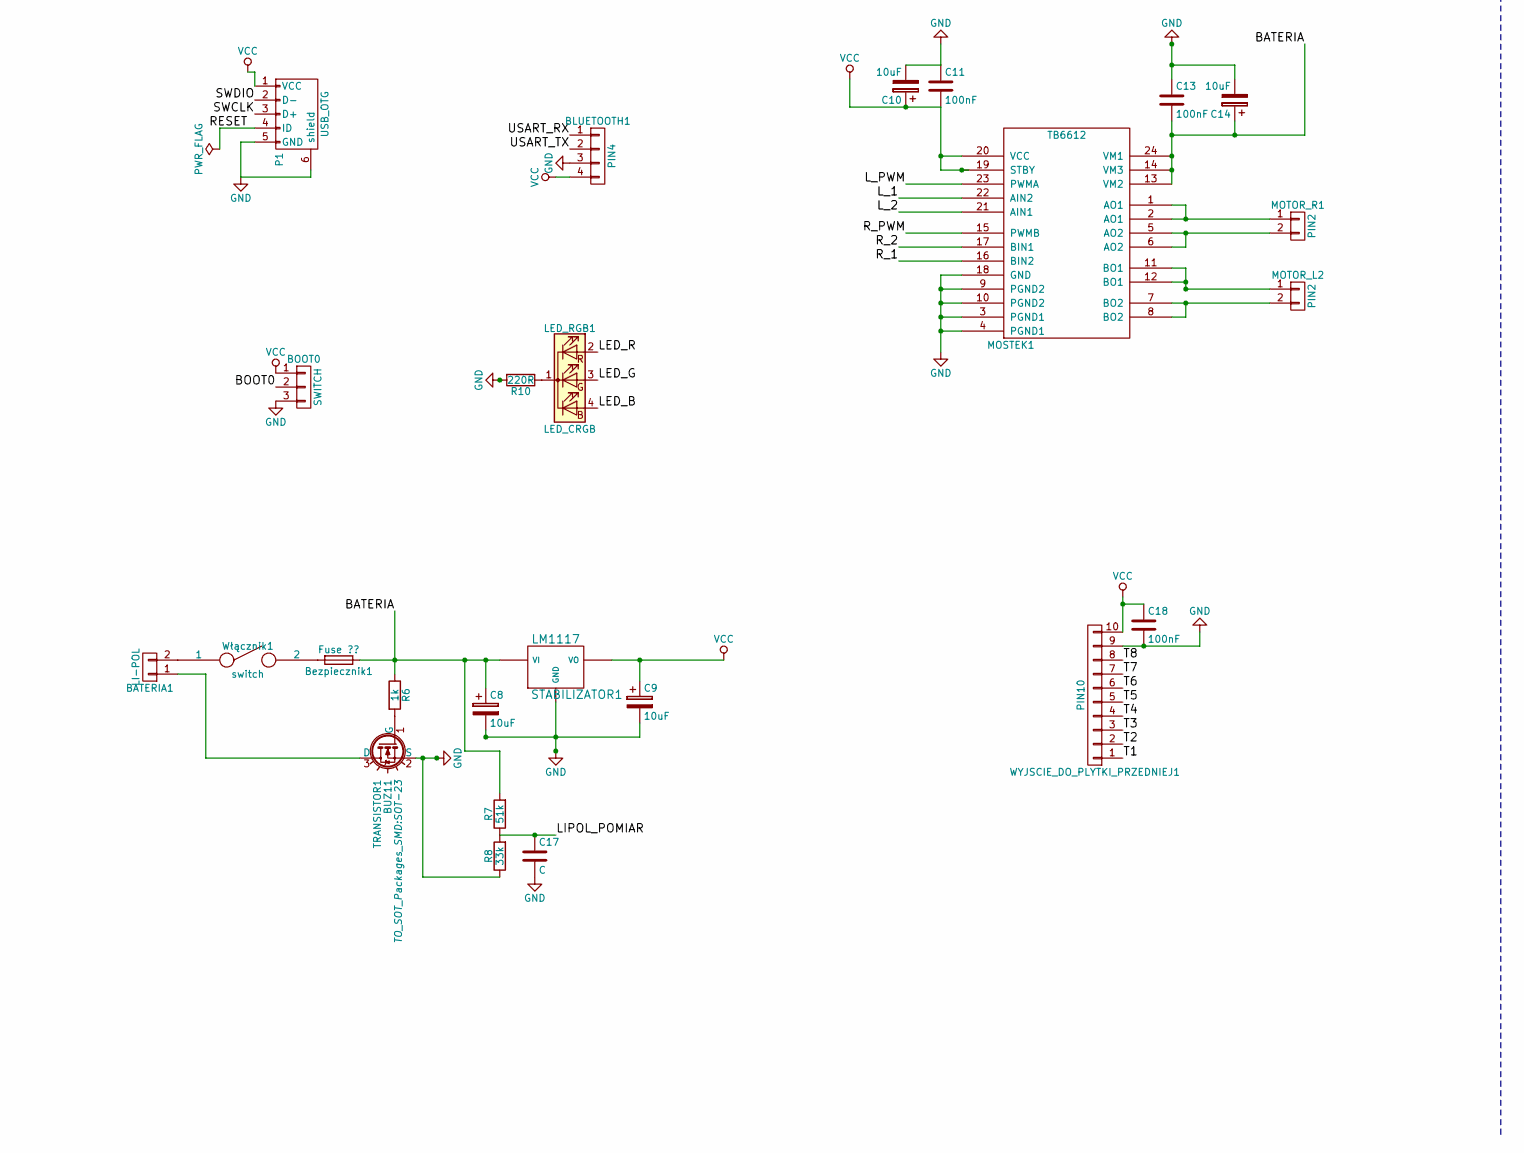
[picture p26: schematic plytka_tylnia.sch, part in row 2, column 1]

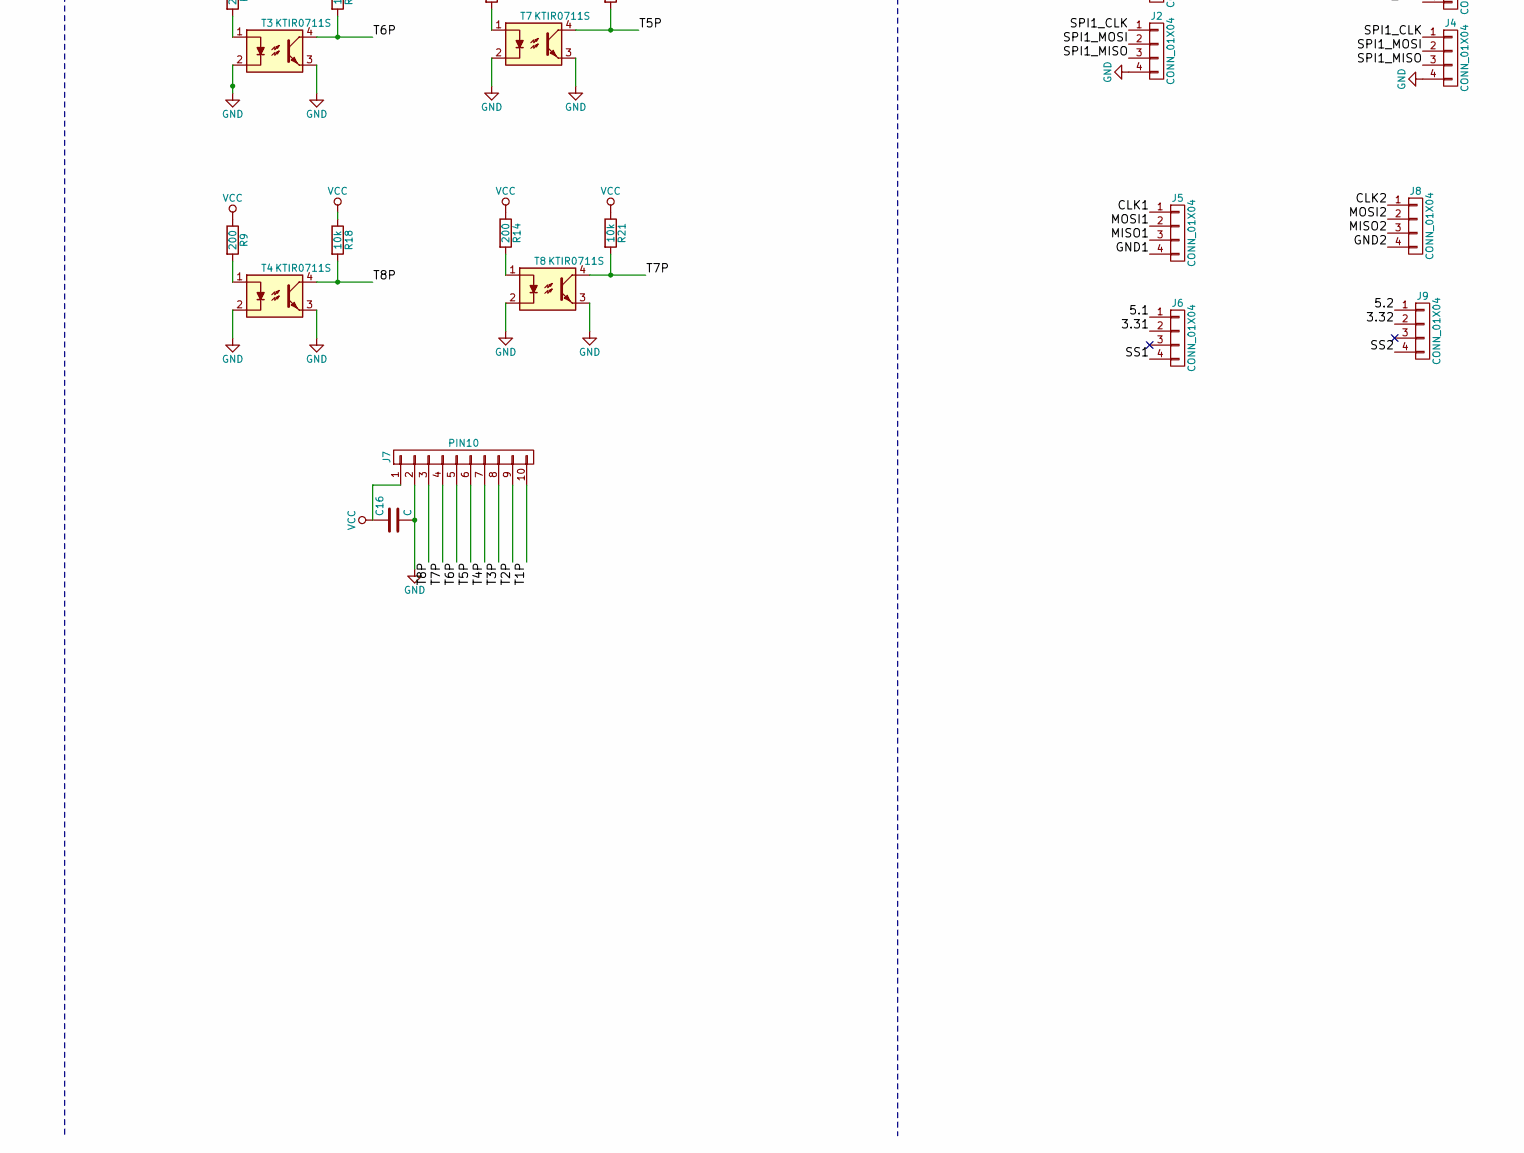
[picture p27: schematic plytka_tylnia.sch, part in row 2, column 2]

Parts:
BATERIA1: LI-POL; zl_zasilania
BLUETOOTH1: PIN4; GoldPin_1x4
BOOT0: SWITCH; Pin_Header_Straight_1x03_Pitch2.00mm
Bezpiecznik1: Fuse ??; Fuse_SMD1206_HandSoldering
C1, C7: 4,7uF; CP_Tantalum_Case-A_EIA-3216-18_Hand
C1.1, C1.2, C2.1, C2.2, C16, C17: C; C_0805_HandSoldering
C2, C3: 22pF; C_0805_HandSoldering
C4: 10nF; C_0805_HandSoldering
C5: 1uF; C_0805_HandSoldering
C6, C11, C12, C13, C18: 100nF; C_0805_HandSoldering
C8, C9, C10, C14: 10uF; CP_Tantalum_Case-A_EIA-3216-18_Hand
J1, J2, J3, J4, J5, J6, J8, J9: CONN_01X04; GoldPin_1x4
J7: PIN10; fpc_10_pin
L1: 10uH; R_0805_HandSoldering
LED_RGB1: LED_CRGB; LED_RGB_0805
MIKROPROCEK1: STM32F051C8Tx; LQFP48
MOSTEK1: TB6612
MOTOR_L2: PIN2; Pin_Header_Straight_1x02_Pitch2.00mm
MOTOR_R1: PIN2; Pin_Header_Straight_1x02_Pitch2.00mm
P1: USB_OTG; USB_Micro-B_Molex-105017-0001
PRZYCISK_RESET1: SW_PUSH; SW_06_SMD
R1, R4, R5, R9, R11, R12, R13, R14: 200; R_0805_HandSoldering
R2, R3, R15, R16, R17, R18, R20, R21, R22: 10k; R_0805_HandSoldering
R6: 1k; R_0805_HandSoldering
R7: 51k; R_0805_HandSoldering
R8: 33k; R_0805_HandSoldering
R10: 220R; R_0805_HandSoldering
R19: 10K; R_0805_HandSoldering
REZONATOR1: HC49-S; Kwarc_SMD_Mini
STABILIZATOR1: LM1117; LM1117_TO-252
START_BUTTON1: PUSH; SW_06_SMD
T1, T2, T3, T4, T5, T6, T7, T8: KTIR0711S
TRANSISTOR1: BUZ11; SOT-23
U1, U2: AS5048A; SOP65P640X120-14N
WYJSCIE_DO_PLYTKI_PRZEDNIEJ1: PIN10; fpc_10_pin
Włącznik1: switch; dip_switch_1

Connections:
/3.31: C1.1.1, C1.2.1, J6.1, J6.2, U1.11 (VDD5V), U1.12 (VDD3V)
/3.32: C2.1.1, C2.2.1, J9.1, J9.2, U2.11 (VDD5V), U2.12 (VDD3V)
/BATERIA: Bezpiecznik1.1, C8.1, C13.2, C14.1, MOSTEK1.13 (VM2), MOSTEK1.14 (VM3), MOSTEK1.24 (VM1), R6.1, R7.2, STABILIZATOR1.1 (VI)
/BOOT0: BOOT0.2, MIKROPROCEK1.44 (BOOT0)
/CLK1: J5.1, U1.2 (CLK)
/CLK2: J8.1, U2.2 (CLK)
/GND1: C1.1.2, C1.2.2, J5.4, U1.13 (GND)
/GND2: C2.1.2, C2.2.2, J8.4, U2.13 (GND)
/LED_B: LED_RGB1.4 (BA), MIKROPROCEK1.18 (PB0/ADC_IN8/TIM1_CH2N/TIM3_CH3/TSC_G3_I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)
/LED_G: LED_RGB1.3 (GA), MIKROPROCEK1.22 (PB11/I2C2_SDA/TIM2_CH4/TSC_G6_IO1)
/LED_R: LED_RGB1.2 (RA), MIKROPROCEK1.21 (PB10/CEC/I2C2_SCL/TIM2_CH3/TSC_SYNC)
/LIPOL_POMIAR: C17.1, MIKROPROCEK1.19 (PB1/ADC_IN9/TIM14_CH1/TIM1_CH3N/TIM3_CH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), R7.1, R8.2
/L_1: MIKROPROCEK1.27 (PB14/SPI2_MISO/TIM15_CH1/TIM1_CH2N/TSC_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), MOSTEK1.22 (AIN2)
/L_2: MIKROPROCEK1.28 (PB15/RTC_REFIN/SPI2_MOSI/TIM15_CH1N/TIM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), MOSTEK1.21 (AIN1)
/L_PWM: MIKROPROCEK1.29 (RCC_MCO/TIM1_CH1/USART1_CK/PA8), MOSTEK1.23 (PWMA)
/MISO1: J5.3, U1.3 (MISO)
/MISO2: J8.3, U2.3 (MISO)
/MOSI1: J5.2, U1.4 (MOSI)
/MOSI2: J8.2, U2.4 (MOSI)
/RESET: MIKROPROCEK1.7 (NRST), P1.4 (ID), PRZYCISK_RESET1.1, R2.2
/R_1: MIKROPROCEK1.31 (TIM17_BKIN/TIM1_CH3/TSC_G4_IO2/USART1_R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), MOSTEK1.16 (BIN2)
/R_2: MIKROPROCEK1.30 (DAC1_EXTI9/TIM15_BKIN/TIM1_CH2/TSC_G4_I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), MOSTEK1.17 (BIN1)
/R_PWM: MIKROPROCEK1.32 (COMP1_OUT/TIM1_CH4/TSC_G4_IO3/USART1_CT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), MOSTEK1.15 (PWMB)
/SPI1_CLK: J2.1, J4.1, MIKROPROCEK1.39 (PB3/I2S1_CK/SPI1_SCK/TIM2_CH2/TSC_G5_IO1)
/SPI1_MISO: J2.3, J4.3, MIKROPROCEK1.40 (PB4/I2S1_MCK/SPI1_MISO/TIM3_CH1/TSC_G5_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)
/SPI1_MOSI: J2.2, J4.2, MIKROPROCEK1.41 (PB5/I2C1_SMBA/I2S1_SD/SPI1_MOSI/TIM16_B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)
/SPI1_SS1: J1.4, MIKROPROCEK1.42 (PB6/I2C1_SCL/TIM16_CH1N/TSC_G5_IO3/USAR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)
/SPI1_SS2: J3.4, MIKROPROCEK1.43 (PB7/I2C1_SDA/TIM17_CH1N/TSC_G5_IO4/USAR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)
/SS1: J6.4, U1.1 (~CSn)
/SS2: J9.4, U2.1 (~CSn)
/SWCLK: BLUETOOTH1.2, MIKROPROCEK1.37 (SYS_SWCLK/USART2_TX/PA14), P1.3 (D+)
/SWDIO: MIKROPROCEK1.34 (IR_OUT/SYS_SWDIO/PA13), P1.2 (D-)
/T1: MIKROPROCEK1.10 (ADC_IN0/COMP1_INM/COMP1_OUT/RTC_TAMP2/S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), WYJSCIE_DO_PLYTKI_PRZEDNIEJ1.1
/T1P: J7.10, R19.2, T5.4
/T2: MIKROPROCEK1.11 (ADC_IN1/COMP1_INP/TIM2_CH2/TSC_G1_IO2/U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), WYJSCIE_DO_PLYTKI_PRZEDNIEJ1.2
/T2P: J7.9, R15.2, T1.4
/T3: MIKROPROCEK1.12 (ADC_IN2/COMP2_INM/COMP2_OUT/TIM15_CH1/T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), WYJSCIE_DO_PLYTKI_PRZEDNIEJ1.3
/T3P: J7.8, R20.2, T6.4
/T4: MIKROPROCEK1.13 (ADC_IN3/COMP2_INP/TIM15_CH2/TIM2_CH4/TS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), WYJSCIE_DO_PLYTKI_PRZEDNIEJ1.4
/T4P: J7.7, R16.2, T2.4
/T5: MIKROPROCEK1.14 (ADC_IN4/COMP1_INM/COMP2_INM/DAC1_OUT1/I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), WYJSCIE_DO_PLYTKI_PRZEDNIEJ1.5
/T5P: J7.6, R22.2, T7.4
/T6: MIKROPROCEK1.15 (ADC_IN5/CEC/COMP1_INM/COMP2_INM/I2S1_CK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), WYJSCIE_DO_PLYTKI_PRZEDNIEJ1.6
/T6P: J7.5, R17.2, T3.4
/T7: MIKROPROCEK1.16 (ADC_IN6/COMP1_OUT/I2S1_MCK/SPI1_MISO/TI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), WYJSCIE_DO_PLYTKI_PRZEDNIEJ1.7
/T7P: J7.4, R21.2, T8.4
/T8: MIKROPROCEK1.17 (ADC_IN7/COMP2_OUT/I2S1_SD/SPI1_MOSI/TIM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), WYJSCIE_DO_PLYTKI_PRZEDNIEJ1.8
/T8P: J7.3, R18.2, T4.4
/USART_RX: BLUETOOTH1.1, MIKROPROCEK1.38 (I2S1_WS/SPI1_NSS/TIM2_CH1/TIM2_ETR/USAR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)
GND: BLUETOOTH1.3, BOOT0.3, C1.2, C2.2, C3.2, C4.2, C5.2, C6.2, C7.2, C8.2, C9.2, C10.2, C11.1, C12.2, C13.1, C14.2, C16.2, C17.2, C18.2, J2.4, J4.4, J7.2, MIKROPROCEK1.1 (VBAT), MIKROPROCEK1.8 (VSSA), MIKROPROCEK1.23 (VSS), MIKROPROCEK1.25 (PB12/SPI2_NSS/TIM1_BKIN/TSC_G6_IO2), MIKROPROCEK1.26 (PB13/SPI2_SCK/TIM1_CH1N/TSC_G6_IO3), MIKROPROCEK1.47 (VSS), MOSTEK1.3 (PGND1), MOSTEK1.4 (PGND1), MOSTEK1.9 (PGND2), MOSTEK1.10 (PGND2), MOSTEK1.18 (GND), P1.5 (GND), P1.6 (shield), PRZYCISK_RESET1.2, R8.1, R10.2, STABILIZATOR1.3 (GND), START_BUTTON1.1, T1.2, T1.3, T2.2, T2.3, T3.2, T3.3, T4.2, T4.3, T5.2, T5.3, T6.2, T6.3, T7.2, T7.3, T8.2, T8.3, TRANSISTOR1.2 (S), WYJSCIE_DO_PLYTKI_PRZEDNIEJ1.9
unnamed: BATERIA1.1, TRANSISTOR1.3 (D)
unnamed: BATERIA1.2, Włącznik1.1
unnamed: Bezpiecznik1.2, Włącznik1.2
unnamed: C2.1, MIKROPROCEK1.5 (PF0/RCC_OSC_IN), REZONATOR1.2
unnamed: C3.1, MIKROPROCEK1.6 (PF1/RCC_OSC_OUT), REZONATOR1.1
unnamed: L1.2, MIKROPROCEK1.9 (VDDA)
unnamed: LED_RGB1.1 (K), R10.1
unnamed: MIKROPROCEK1.33 (COMP2_OUT/TIM1_ETR/TSC_G4_IO4/USART1_DE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), R3.2, START_BUTTON1.2
unnamed: MOSTEK1.1 (AO1), MOSTEK1.2 (AO1), MOTOR_R1.1
unnamed: MOSTEK1.5 (AO2), MOSTEK1.6 (AO2), MOTOR_R1.2
unnamed: MOSTEK1.7 (BO2), MOSTEK1.8 (BO2), MOTOR_L2.2
unnamed: MOSTEK1.11 (BO1), MOSTEK1.12 (BO1), MOTOR_L2.1
unnamed: R1.2, T1.1
unnamed: R4.2, T2.1
unnamed: R5.2, T3.1
unnamed: R6.2, TRANSISTOR1.1 (G)
unnamed: R9.2, T4.1
unnamed: R11.2, T5.1
unnamed: R12.2, T6.1
unnamed: R13.2, T7.1
unnamed: R14.2, T8.1
VCC: BLUETOOTH1.4, BOOT0.1, C1.1, C4.1, C5.1, C6.1, C7.1, C9.1, C10.1, C11.2, C12.1, C16.1, C18.1, J1.1, J1.2, J3.1, J3.2, J7.1, L1.1, MIKROPROCEK1.24 (VDD), MIKROPROCEK1.48 (VDD), MOSTEK1.19 (STBY), MOSTEK1.20 (VCC), P1.1 (VCC), R1.1, R2.1, R3.1, R4.1, R5.1, R9.1, R11.1, R12.1, R13.1, R14.1, R15.1, R16.1, R17.1, R18.1, R19.1, R20.1, R21.1, R22.1, STABILIZATOR1.2 (VO), WYJSCIE_DO_PLYTKI_PRZEDNIEJ1.10

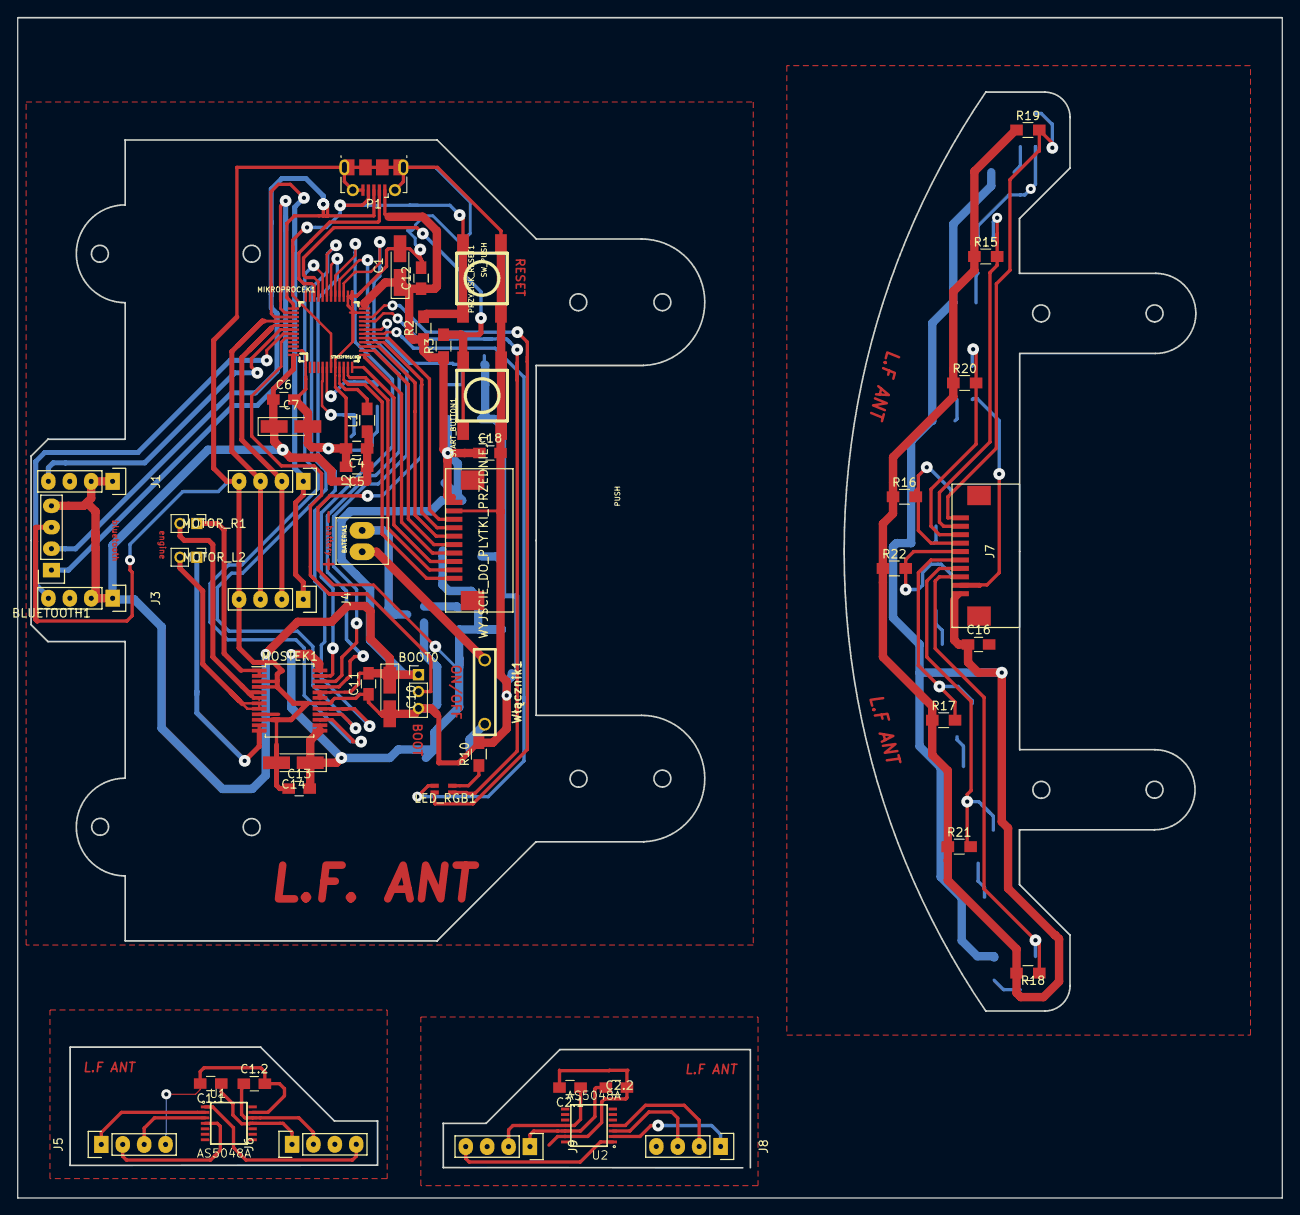
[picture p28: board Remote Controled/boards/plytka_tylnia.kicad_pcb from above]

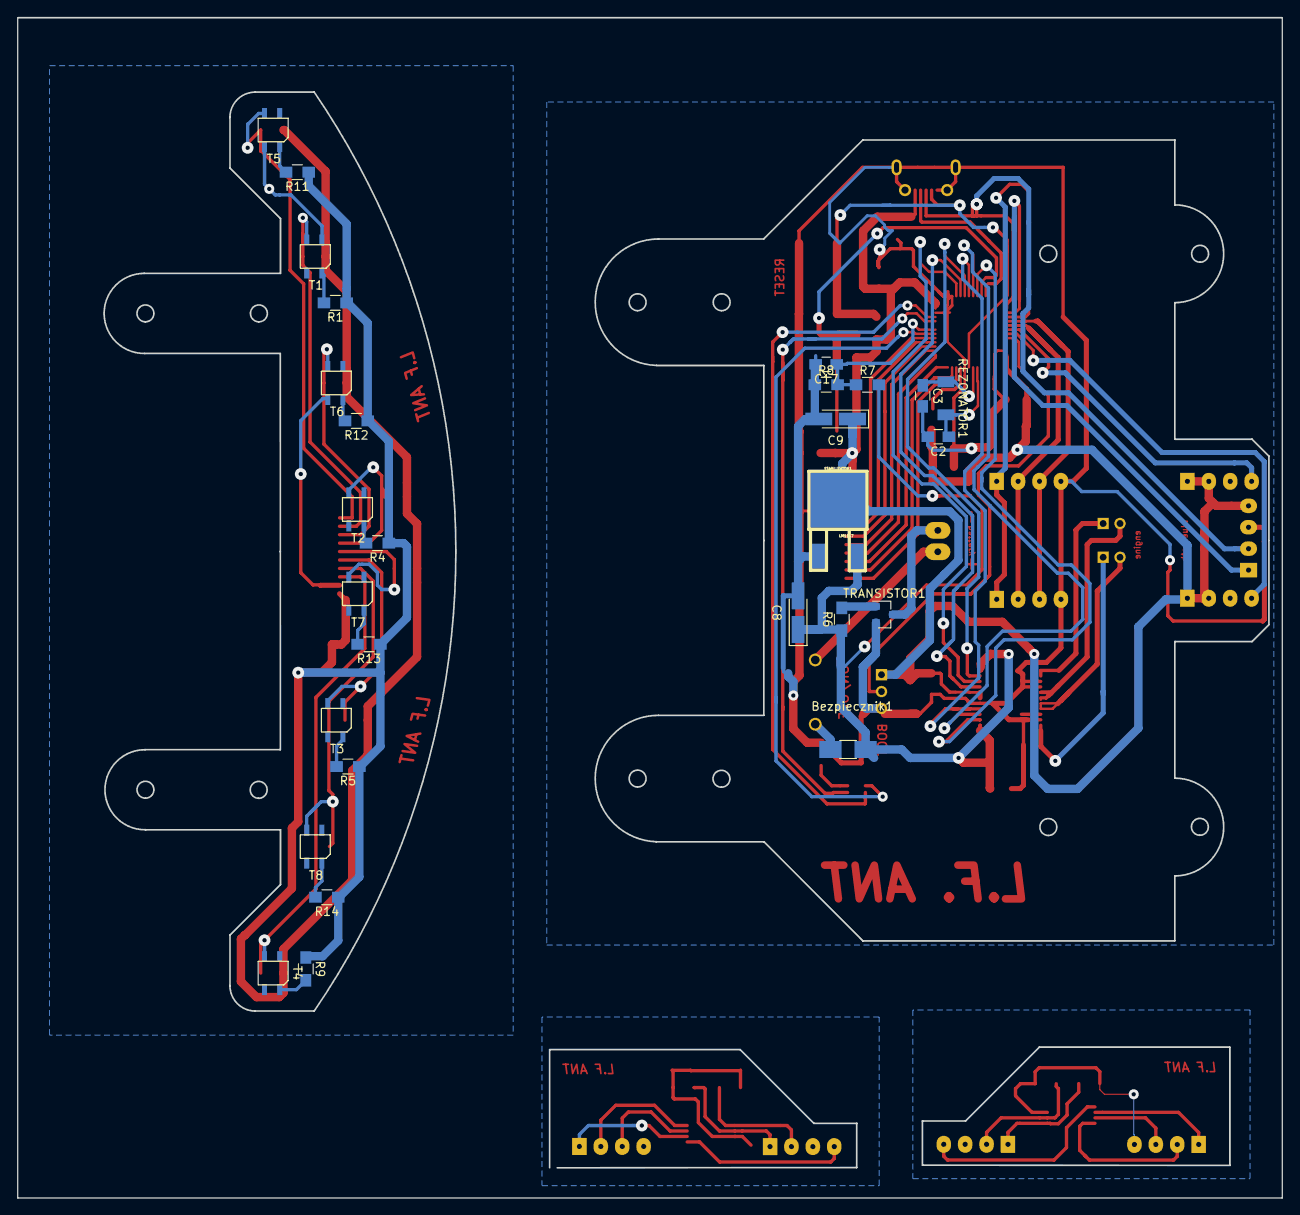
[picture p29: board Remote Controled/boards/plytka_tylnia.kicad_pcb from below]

Board: 2 copper layers, 150.0 x 140.0 mm, 80 parts (28 on the bottom side), 72 nets.

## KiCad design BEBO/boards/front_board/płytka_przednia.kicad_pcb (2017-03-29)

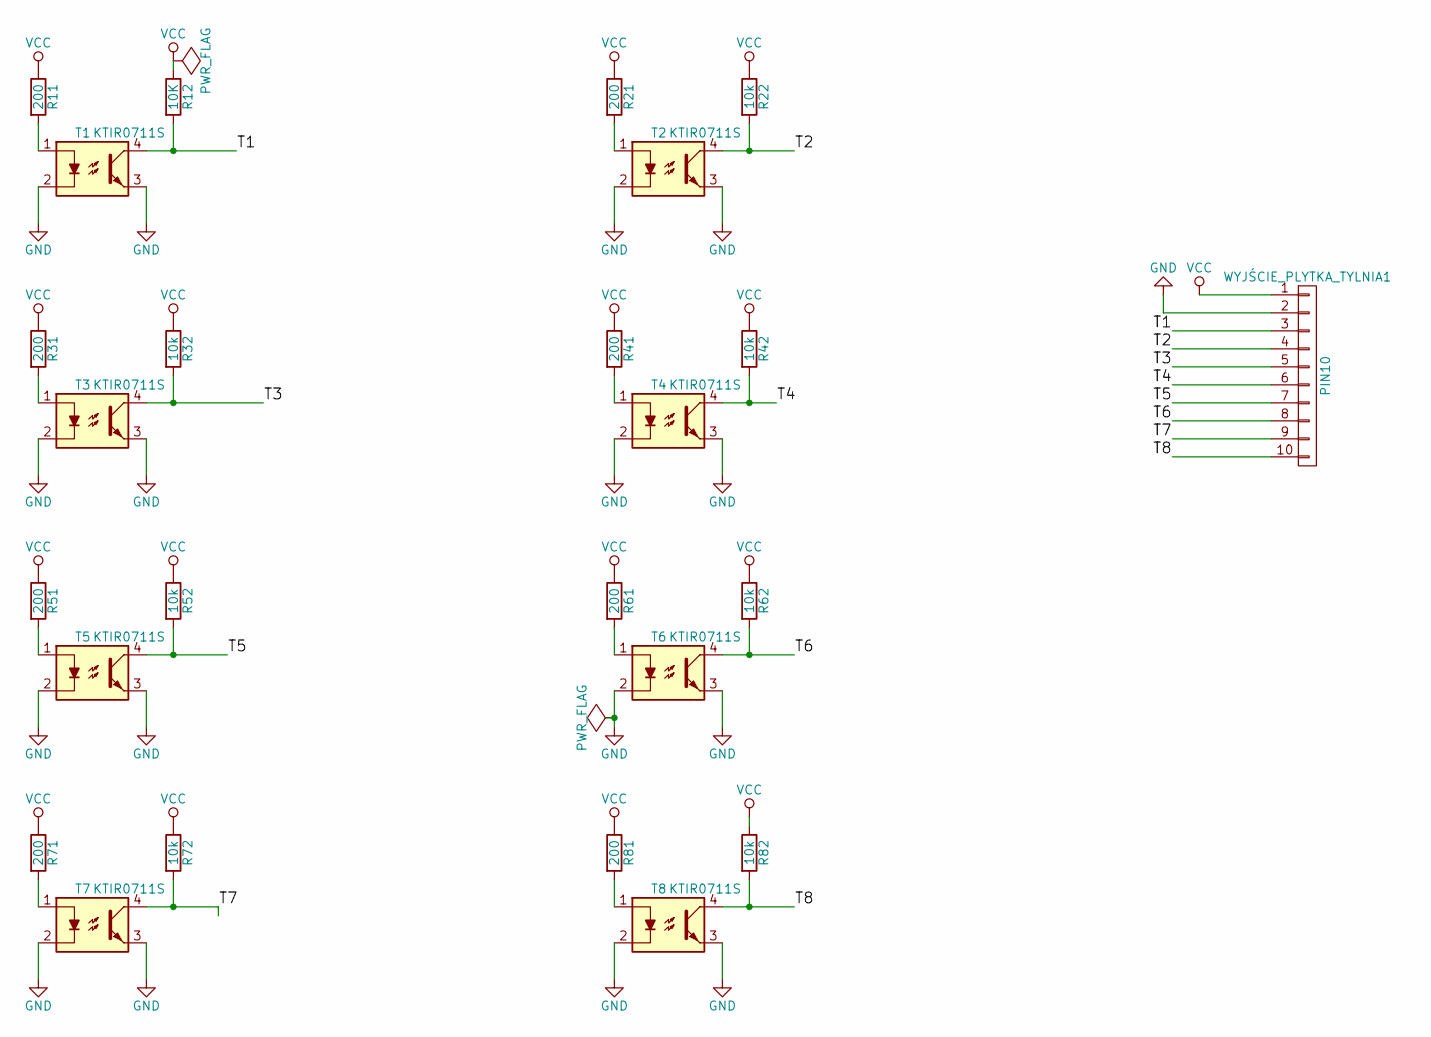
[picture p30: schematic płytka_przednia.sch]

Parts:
R11, R21, R31, R41, R51, R61, R71, R81: 200; R_0805_HandSoldering
R12: 10K; R_0805_HandSoldering
R22, R32, R42, R52, R62, R72, R82: 10k; R_0805_HandSoldering
T1, T2, T3, T4, T5, T6, T7, T8: KTIR0711S
WYJŚCIE_PLYTKA_TYLNIA1: PIN10; fpc_10_pin

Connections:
/T1: R12.2, T1.4, WYJŚCIE_PLYTKA_TYLNIA1.3
/T2: R22.2, T2.4, WYJŚCIE_PLYTKA_TYLNIA1.4
/T3: R32.2, T3.4, WYJŚCIE_PLYTKA_TYLNIA1.5
/T4: R42.2, T4.4, WYJŚCIE_PLYTKA_TYLNIA1.6
/T5: R52.2, T5.4, WYJŚCIE_PLYTKA_TYLNIA1.7
/T6: R62.2, T6.4, WYJŚCIE_PLYTKA_TYLNIA1.8
/T7: R72.2, T7.4, WYJŚCIE_PLYTKA_TYLNIA1.9
/T8: R82.2, T8.4, WYJŚCIE_PLYTKA_TYLNIA1.10
GND: T1.2, T1.3, T2.2, T2.3, T3.2, T3.3, T4.2, T4.3, T5.2, T5.3, T6.2, T6.3, T7.2, T7.3, T8.2, T8.3, WYJŚCIE_PLYTKA_TYLNIA1.2
unnamed: R11.2, T1.1
unnamed: R21.2, T2.1
unnamed: R31.2, T3.1
unnamed: R41.2, T4.1
unnamed: R51.2, T5.1
unnamed: R61.2, T6.1
unnamed: R71.2, T7.1
unnamed: R81.2, T8.1
VCC: R11.1, R12.1, R21.1, R22.1, R31.1, R32.1, R41.1, R42.1, R51.1, R52.1, R61.1, R62.1, R71.1, R72.1, R81.1, R82.1, WYJŚCIE_PLYTKA_TYLNIA1.1

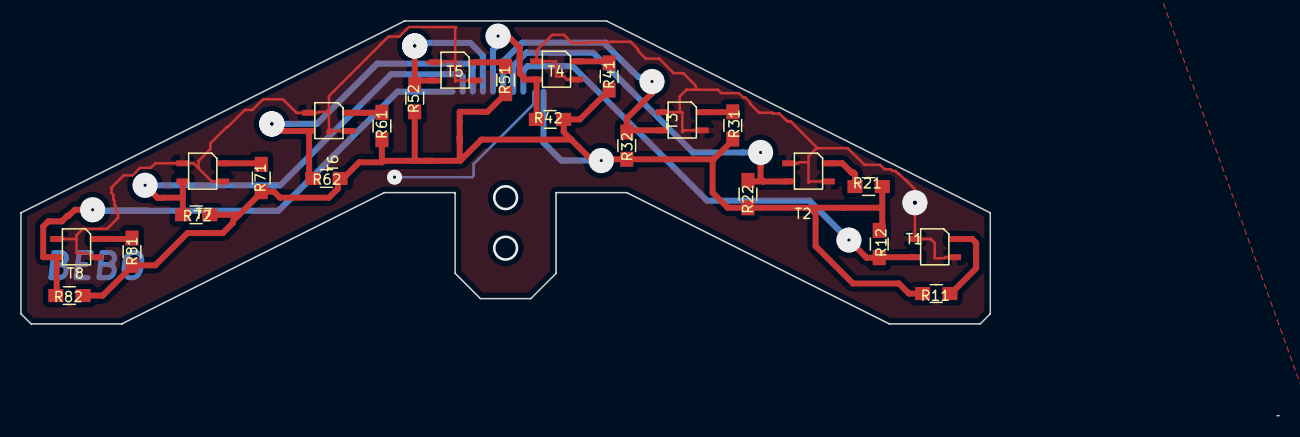
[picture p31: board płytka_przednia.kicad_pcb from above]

Board: 2 copper layers, 96.0 x 30.0 mm, 25 parts (1 on the bottom side), 18 nets.

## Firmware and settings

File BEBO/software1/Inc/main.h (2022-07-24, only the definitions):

#define T1_Pin GPIO_PIN_0
#define T1_GPIO_Port GPIOA
#define T2_Pin GPIO_PIN_1
#define T2_GPIO_Port GPIOA
#define T3_Pin GPIO_PIN_2
#define T3_GPIO_Port GPIOA
#define T4_Pin GPIO_PIN_3
#define T4_GPIO_Port GPIOA
#define T5_Pin GPIO_PIN_4
#define T5_GPIO_Port GPIOA
#define T6_Pin GPIO_PIN_5
#define T6_GPIO_Port GPIOA
#define T7_Pin GPIO_PIN_6
#define T7_GPIO_Port GPIOA
#define T8_Pin GPIO_PIN_7
#define T8_GPIO_Port GPIOA
#define LED_Pin GPIO_PIN_0
#define LED_GPIO_Port GPIOB
#define START_BUTTON_Pin GPIO_PIN_2
#define START_BUTTON_GPIO_Port GPIOB
#define L_TYL_Pin GPIO_PIN_14
#define L_TYL_GPIO_Port GPIOB
#define L_PRZOD_Pin GPIO_PIN_15
#define L_PRZOD_GPIO_Port GPIOB
#define L_PWM_Pin GPIO_PIN_8
#define L_PWM_GPIO_Port GPIOA
#define R_PRZOD_Pin GPIO_PIN_9
#define R_PRZOD_GPIO_Port GPIOA
#define R_TYL_Pin GPIO_PIN_10
#define R_TYL_GPIO_Port GPIOA
#define R_PWM_Pin GPIO_PIN_11
#define R_PWM_GPIO_Port GPIOA
#define BUTTON_Pin GPIO_PIN_5
#define BUTTON_GPIO_Port GPIOB

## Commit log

2017-03-30 bez enkoderow
    [plytka_tylnia.sch]
2017-04-05 zrobiony przełącznik boot0
    [plytka_tylnia.sch]
2017-04-17 tył do druku
    [enkodery.kicad_pcb, plytka_tylnia.kicad_pcb, plytka_tylnia.sch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]
2017-04-17 nazwy przyciskow
    [plytka_tylnia.kicad_pcb]
2017-04-17 warstwa dolna okrag
    [plytka_tylnia.kicad_pcb]
2017-04-18 wejscie turbiny tylem
    [plytka_tylnia.kicad_pcb]
2017-04-24 poprawiony echo/trig
    [enkodery.kicad_pcb, plytka_tylnia.kicad_pcb, plytka_tylnia.sch]
2017-04-26 Usuniecie zlacza 3x2
    [plytka_tylnia.kicad_pcb]
2017-05-02 zabezpieczenie przed odwrotną polaryzacją, ścieżki spi 0.6 , zwykle 0.4 zasilanie 1
    [plytka_tylnia.kicad_pcb, plytka_tylnia.sch]
2017-05-08 kondensatory spolaryzowane na tantalowe
    [plytka_tylnia.kicad_pcb, plytka_tylnia.sch]
2017-05-08 lista czesci
    [części.xlsx]
2017-05-08 skompletowane czesci, wybrane rezystory, kondensator przy wejsciu
    [części.xlsx, plytka_tylnia.kicad_pcb, plytka_tylnia.sch]
2017-05-09 zamówienie z elektroparku
    [części.xlsx]
2017-05-15 archiwum ze złego projektu + drukowanie
    [enkodery.sch, plytka_tylnia.kicad_pcb]
2017-05-15 skończona płytka bez turbiny do wydruku
    [plytka_tylnia.kicad_pcb, plytka_tylnia.sch, płytka_przednia.kicad_pcb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]
2017-05-22 poprawiona, odchudzona, zaokraglona
    [plytka_tylnia.kicad_pcb, plytka_tylnia.sch]
2017-05-22 zmniejszony obwod plytki
    [plytka_tylnia.kicad_pcb]
2017-05-23 zmienione przelotki na 1,4/0,5
    [bez_nazwyBU.kicad_pcb, enkodery.kicad_pcb, enkodery.sch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]
2017-05-25 raster goldpin na 2,54, scieżki wokół procka i mostka na 0,3 mm,
    [plytka_tylnia.kicad_pcb, plytka_tylnia.sch]
2017-06-02 dodanie mocowania magnesow w inventorze
    [LFANT.cfg, mocowania_magnesów.ipt, plytka_tylnia.kicad_pcb]
2022-08-28 Add README
    [BEBO_MX.cfg, LFANT.cfg, LM351x_kalkulator.xls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]

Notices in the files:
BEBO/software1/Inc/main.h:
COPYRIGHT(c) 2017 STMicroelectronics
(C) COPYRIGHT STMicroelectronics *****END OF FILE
